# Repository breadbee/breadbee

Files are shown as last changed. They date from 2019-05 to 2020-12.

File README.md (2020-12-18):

# Breadbee

A very small, 32mm x 30mm, ARM Cortex A7 development board that costs about ~$10
to make in low quantities and can be assembled at home with a cheap hot air rework
station. With a [small adapter socket](./hivee) it can be mounted vertically in a standard breadboard.

The breadbee is based on a relatively unknown IP camera SoC, the MSC313E, from a company called MStar
(now part of MediaTek as a subsidiary called SigmaStar).
You might have never heard of MStar but you probably have one of their chips in your TV.

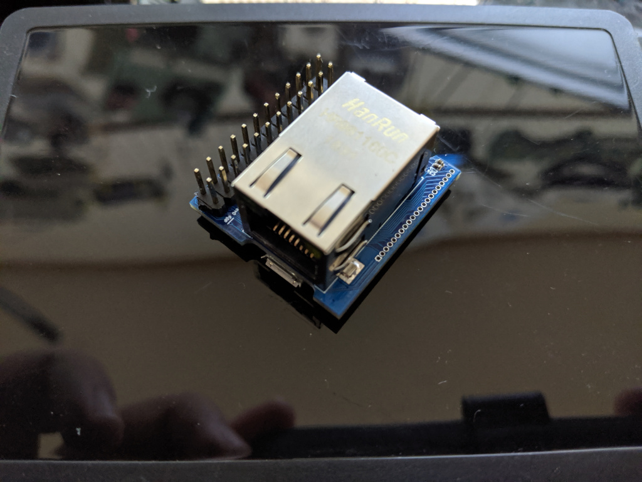
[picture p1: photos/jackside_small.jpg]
Breadbee number one


## Features

These are features that are working:

- ~1GHz Cortex A7 CPU with NEON etc[0].
- 64MB DDR2 (Probably DDR2-1333)
- 128KB SRAM (88KB if you use a MSC313(no e).
- [Bootable, memory mapped SPI-NOR](https://github.com/fifteenhex/linux/blob/msc313e/drivers/spi/spi-msc313-isp.c)
- 100Mbit ethernet.
- [4 x 10bit ADC channels](https://github.com/fifteenhex/linux/blob/msc313e/drivers/iio/adc/msc313e_sar.c)
- [2 x SPI](https://github.com/fifteenhex/linux/blob/msc313e/drivers/spi/spi-msc313.c)
- [1 x I2C (there is possibly one more)](https://github.com/fifteenhex/linux/blob/msc313e/drivers/i2c/busses/i2c-msc313e.c)
- [3 UARTs](https://github.com/fifteenhex/linux/blob/b3c521f8f30c9cc6f9f9c5c87429336d4756dcca/drivers/tty/serial/8250/8250_dw.c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) [1]
- Lots of GPIO. At least one pin with wake up support.
- [RTC](https://github.com/fifteenhex/linux/blob/msc313e/drivers/rtc/rtc-msc313e.c)
- [WDT](https://github.com/fifteenhex/linux/blob/msc313e/drivers/watchdog/msc313e_wdt.c)
- [3 x Timer](https://github.com/fifteenhex/linux/blob/msc313e/drivers/clocksource/timer-msc313e.c)
- [8 x PWM](https://github.com/fifteenhex/linux/blob/msc313e/drivers/pwm/pwm-msc313e.c)
- [SD/SDIO interface](https://github.com/fifteenhex/linux/blob/msc313e/drivers/mmc/host/mstar-fcie.c)
- 2 x ["byte" dma controller](https://github.com/fifteenhex/linux/blob/msc313e/drivers/dma/mstar/mstar-msc313-bdma.c)
- USB PHY
- USB host/device mux
- Faraday FUSBH200 USB *ehci* host controller
- On die temperature sensor. (sorta)
- Hardware RNG. (quality unknown)
- SHA engine. (Runs, not wired to the kernel)
- 8051 "house keeping" MCU. (Basic remoteproc driver)

[0] MStar says it's 800MHz but their own cpufreq code says they clock it to 1GHz
Clocking up to 1.1GHz works fine running dhrystone for hours but causes random lock ups if the spi nor controller and ethernet are fighting for bus access.
[1] One UART is used by the serial console, two more are available via muxing. 

 The chip has a bunch of stuff in it that isn't supported yet:
 - [MUSB USB device controller](https://github.com/fifteenhex/linux/blob/msc313e/drivers/usb/musb/mstar.c)
 - Camera interface, h264 encoder, mjpeg etc.
 - Audio ADC/DAC
 - [Crypto engine](https://github.com/fifteenhex/linux/blob/msc313e/drivers/crypto/msc313-aesdma.c) that seems to be able to do AES encrypted DMA transfers, memory mapped AES encryption etc
 - Some sort of IR decoder that can wake the chip up based on the IR codes it sees.
 - 6 byte unique device ID and efuse for key storage
 - [command queue dma controller](https://github.com/fifteenhex/linux/blob/msc313e/drivers/dma/mstar/mstar-msc313-cmdq.c)

It's full of flashy magic!

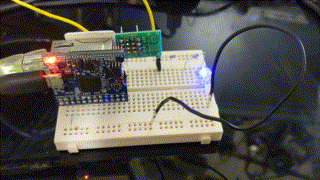
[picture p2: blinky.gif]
PWM blinky


## Power consumption

According to a Kyoritsu KEW 1062 inline with the vbus of a usb cable:

| state | Ethernet on | RTC wake | value |
|---|---|---|---|
| Booted idle  | yes | N/A | 138mA |
| Booted idle  | no | N/A | 113mA |
| Memory sleep | | Yes | 12mA  |

## Board Revisions

- Rev0 - Original version, works.
- Rev1 - Same as rev0 basically but the QFN80 footprint is slightly fixed to not have very thin pads on one side. Rev1 has one weird pad on the QFN80 footprint and an overlapping extra trace on one of the USB signals.

## Motivations

- Networked microcontrollers are a disaster waiting to happen; Many solutions - even commercial ones - use LWIP as the TCP/IP stack with no intention of actually maintaining it, use relatively unknown TLS libraries because of lack of memory, have no memory protection, no isolation between the moving parts.

- There are no solutions yet that can run a real OS like Linux that can be integrated by hobbyists into boards from cheap PCB vendors that don't have show stopping limitations. I.e. the AllWinner V3s is very similar to the SoC used here but it only has one SPI controller that is lost as soon as you put SPI NOR on it. The MSC313E has just enough of the usual microcontroller peripherals to make it useful, comes in a (relatively) easy to work with QFN package, is tiny and costs ~$4.
It is a bit harder to integrate into your designs than a microcontroller that requires a single power supply but all of the information you would need to do so is right here. The schematic for the breadbee is incredibly simple.

- There are single board computers out there that have more cores, more memory etc and are still around $10 but they are over kill for applications where even an ESP32 has enough horse power and they aren't usually something you can integrate into your project without reserving considerable space.

- Why not? The MSC313E is a Cortex-A so getting Linux running from scratch was relatively simple. The peripherals are super weird in places but not totally insane.

## But where's the WiFi!>!!111

The breadbee is meant to be a "minimum viable product" to get the ball rolling. It's impossible to write drivers for the SDIO controller or USB needed for WiFi without a platform to work on. Breadbee is that platform. Once SDIO works there will be an Ampak AP6212 based module to add wifi to breadbees and maybe a respin of the breadbee with the ethernet jack replaced with an Ampak module. 

A simpler alternative consists in using an already supported USB-to-WiFi PCB module given that the breadbee's USB host controller already works fine. This project is documented here.

## Can I have one.. where do I get the chips..

- If you ask very nicely and you are willing to do something like write a nice python library or flesh out drivers for the board it's possible you can have one of the prototype boards for FREE! Get in touch!

- ~~If you just want to buy one the intention is to put the board up on a crowd sourcing site at some point. When that happens that information will be here.~~ [crowdsupply](https://www.crowdsupply.com/daniel-palmer/breadbee) will eventually be selling premade boards. This might take a while though.

- If you want chips to integrate into your own projects and don't have contacts in Shenzhen to get them get in touch and we'll figure something out. If you want 2080 of them getting them isn't a problem. If you want one or two I have a small supply. If the crowd sourcing happens and there is enough money left to buy extra chips to distribute in more accessible ways I will. Since April 2020 chips have now also started to turn on up ebay.

- The gerbers have been uploaded to [OSH park (rev1)](https://oshpark.com/shared_projects/lQ6wt3Dk) ready to order. [OSH park (rev0)](https://oshpark.com/shared_projects/slorKWK0)

## Software

Note that this is all in flux right at the moment. These repos are getting rebase'd fairly often.

### U-boot

There is a basic port of u-boot that so far take over from the MStar IPL and load a kernel from the SPI NOR, write it etc.
See boot process below for more details.

https://github.com/fifteenhex/u-boot/tree/msc313

### Kernel

All of the above features work to some degree in the work tree. Mainlining is in progress but will take time.
For more info please see the linux-chenxing.org [page about mainlining](http://linux-chenxing.org/mainlining.html).

### Buildroot

Combines the u-boot and kernel above with a root filesystem and generates flashable images.
There are some small pieces of a board configuration application called "beecfg" to setup pinmuxing etc.

https://github.com/fifteenhex/breadbee_buildroot

## BoM

[Google Sheet](https://docs.google.com/spreadsheets/d/1FwoQdfAULd6vKPnkrVnFDfQQs8OdsqdwefH3aLVehPo)

## Pin Table

### J2 - Main 2.54mm header

| interrupt | 5v tolerant | notes | alt functions | name |  # |  # | name | alt functions | notes | 5v tolerant | interrupt |
|---|---|---|---|---|----|----|---|---|---|---|---|
| | | | | +5v |  1 | 2  | +3v3 | | | | |
| | | | | gnd |  3 | 4  | pm_gpio4  | | [0] | yes | yes |
| | | | | i2c1_scl  |  5 | 6  | i2c1_sda  | | | | |
| yes | | | ej_tck, pwm4 | spi0_cz |  7 | 8  | spi0_ck | ej_tms, pwm5 | | | yes |
| yes | | | ej_tdo, pwm6 | spi0_di |  9 | 10 | spi0_do | ej_tdi, pwm7 | | | yes |
| | yes | | | sar_gpio2 | 11 | 12 | sar_gpio3 | | | yes | |
| | yes | | | sar_gpio1 | 13 | 14 | sar_gpio0 | | | yes | |
| | yes | cs | spi0_cz, pwm0 | fuart_rx  | 15 | 16 | fuart_tx  | spi0_ck, pwm1 | clk | yes | |
| | yes | mosi, [1] | spi0_di, pwm2, uart1_rx | fuart_cts | 17 | 18 | fuart_rts | spi0_do, pwm3, uart1_tx | miso | yes | |
| | | | | sr_io7 | 19 | 20 | sr_io6 | | | | |
| | | | | sr_io5 | 21 | 22 | sr_io4 | | | | |
| | | | | sr_io3 | 23 | 24 | sr_io2 | | | | |

0: This is a special pin that has to be explictly unlocked to be set. It seems to be intended for powering down the main CPU. It might move on rev1.

1 - When fuart is mux'd in it's also possible to mux'in uart1 and get a working rx only
    second uart here.

### J4 - Misc/High speed interfaces

* Note the USB and SD/SDIO are not guaranteed to work as literally no care was taken to route those signals properly on rev0. 

| name | #  | alt functions | 5v tolerant | interrupt | notes |
|---|----|---|---|---|---|
| +3v3 | 1  | | | | |
| sd_d3 | 2  | spi1_do | yes | | miso  |
| sd_d2 | 3  | spi1_di | yes | | mosi  |
| sd_d1 | 4  | spi1_ck | yes | | clk |
| sd_d0 | 5  | spi1_cz | yes | | cs |
| sd_cmd | 6  | | yes | | |
| sd_clk | 7  | | yes | | |
| pm_sd_cdz | 8  | | | yes | |
| gnd | 9  | | | | |
| +5v | 10 | | | | |
| usb_dm | 11 | | | | |
| usb_dp | 12 | | | | |
| gnd | 13 | | | | |
| sr_io15 | 14 | | | | |
| sr_io14 | 15 | | | | |
| sr_io13 | 16 | | | | |
| sr_io12 | 17 | | | | |
| sr_io11 | 18 | | | | |
| sr_io10 | 19 | | | | |
| sr_io9 | 20 | | | | |
| sr_io8 | 21 | | | | |

### Test Points

- The audio pins are broken out to a series of test points on the left side of the parts size of the board.
- pm_irin is broken out to a test point on the ethernet jack side of the board.

## Using JTAG

JTAG is enabled at boot up on the spi0 pins by the u-boot SPL.

## More technical info

[linux-chenxing](http://linux-chenxing.org) has more info about mstar/sigmastar socs.

## Articles etc

[A nice blog entry from Willy about his experience building boards](https://wtarreau.blogspot.com/2020/09/breadbee-build-your-own-single-board.html)

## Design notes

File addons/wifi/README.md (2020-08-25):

# How to simply add WiFi to a breadbee

This is far from being of high quality, but provided little effort, it is possible to add a simple WiFi module to the breadbee.

There are a wide variety of cheap USB modules provided as a small 12.3x13mm PCB with 4 pins on one side and 2 on the other one. These modules work from 3.3V and are connected via USB. Usually they do not have any antenna but one can be connected to the two pins on one side.

Such modules are widely used in WiFi cameras and various consumer appliances, and are usually available from $1.50 to $5.00 depending on the modules. Just search for RTL8188EUS, RTL8188ETV, RTL8188FTV, MT7601U to find a few such devices. Most of them use the exact same footprint and pinout.

The breadbee board features a USB 2.0 controller with a port accessible on the J4 connector:

Pin |  Function
----|-----------
  1 |   +3.3V
 11 |   USB-DM
 12 |   USB-DP
 13 |   GND

Modules which contain a connector can be directly connected to these pins using 4 wires, as shown below:

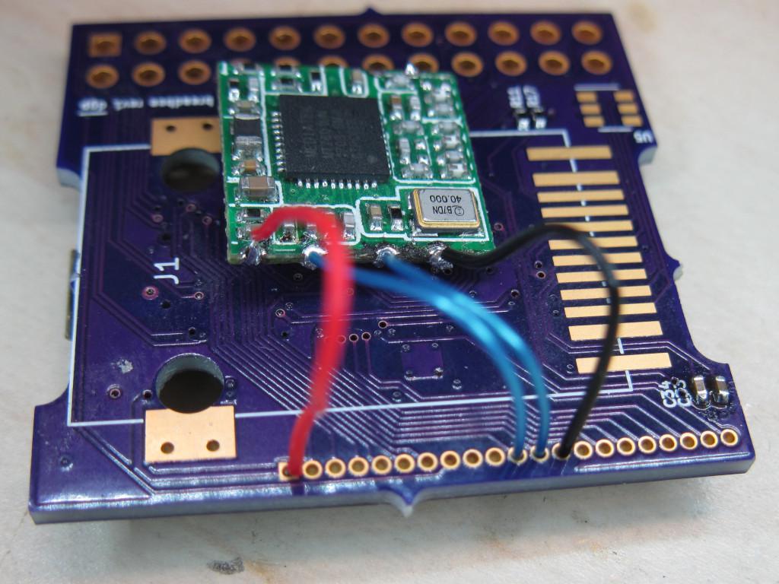
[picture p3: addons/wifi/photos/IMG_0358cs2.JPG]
on the board without RJ45
  

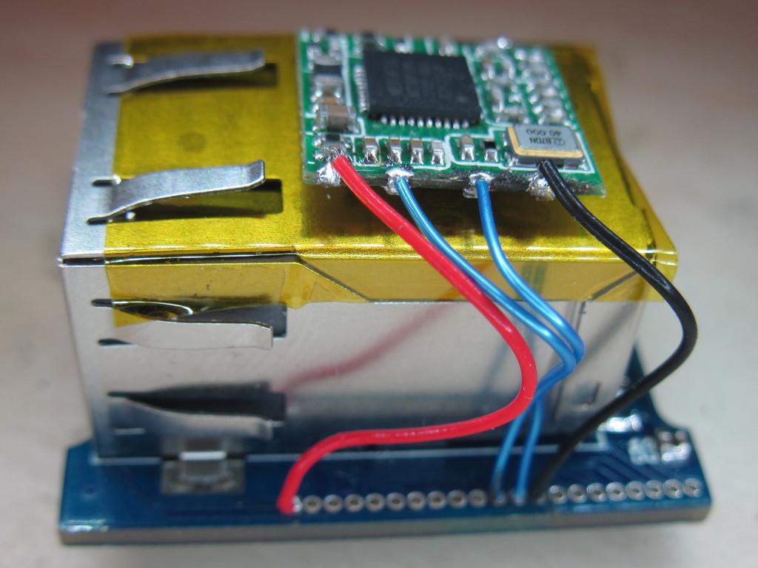
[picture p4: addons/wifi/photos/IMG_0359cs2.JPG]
on the board with RJ45
  

In order to get a cleaner assembly, it is recommended instead to build a breakout board for the module. This is what is proposed in this directory.

The board was designed using Eagle CAD, for which the files are available in the cad directory but the schematic and board layout are also provided as PDF and PNG in the output directory. The board contains a PCB-printed antenna. These antennas can be efficient but are quite complex to design because they depend on the PCB's material and thickness, and the surrounding metal parts. There is a widely available literature on the subject but given the author had no experience there, a first quick-and-dirty attempt was made, losely inspired by the following documents after carefully studying them, and taking into account the constraints of the PCB's size and the fact that the one used here was single-sided:
 - https://www.nxp.com/docs/en/nxp/application-notes/AN11994.pdf
 - http://www.idc-online.com/technical_references/pdfs/electrical_engineering/A%20Highly%20Reliable%20Platform.pdf
 - https://www.cypress.com/documentation/application-notes/an91445-antenna-design-and-rf-layout-guidelines
 - https://www.autodesk.com/products/eagle/blog/everyday-app-note-design-efficient-antenna-rf-layout/
 - https://e2e.ti.com/support/wireless-connectivity/bluetooth/f/538/t/626343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

The board was made using cheap 1.6mm FR4 PCB and provided great results (mesured as the ability to connect and maintain a correct TCP transfer rate at a given distance). Without any antenna, such boards barely connect more than 5-10 meters away on the same floor. With the PCB's antenna, it was possible to maintain roughly 20-25 Mbps between two different stairs.

It is important to make sure the board will be printed to the appropriate dimensions: the J4 connector has a 1mm pitch, and even a 1% error would cause 0.1mm error over 1cm and could be an issue to connect the pins while keeping the boards perfectly tight. It is wise to verify the alignment when drilling the 4 holes (0.4 to 0.5mm max):

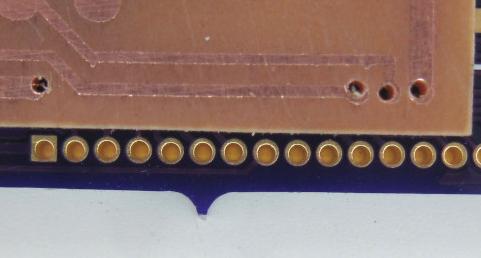
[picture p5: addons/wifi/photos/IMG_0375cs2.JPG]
aligning the boards
  

Then the board may completely cover the J4 connector to keep wires short:

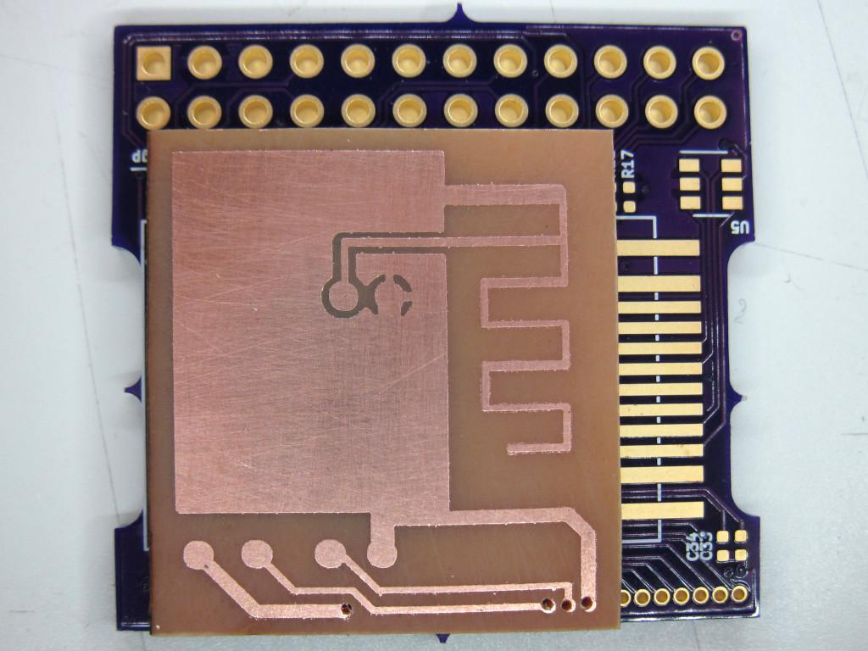
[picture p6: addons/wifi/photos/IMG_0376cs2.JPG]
boards stacked
  
 
The module just needs to be soldered on 6 points. It's recommended to make sure that no contact may be made against the ground plane underneath the module. In case of doubt, a small piece of Kapton tape may be placed between the two, or the module can be kept slightly elevated during soldering.

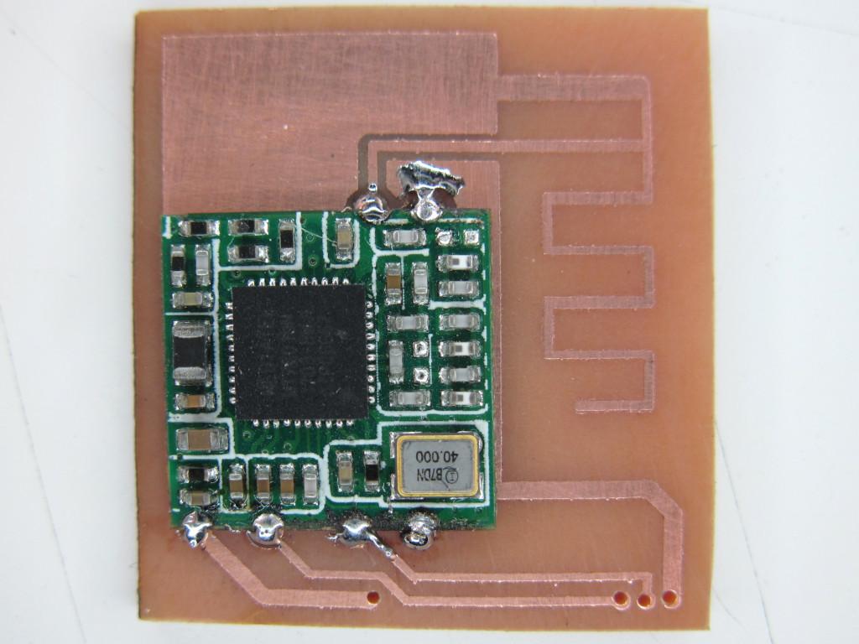
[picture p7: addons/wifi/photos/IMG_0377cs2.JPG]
module installed on bare board
  

The resulting assembly can then be pressed against the breadbee and connected using resistor tails. Alternately, it may be placed on top of the RJ45 connector using short wires. It would also be possible to place it on the SoC side, but in this case it is important to be very careful about insulation.

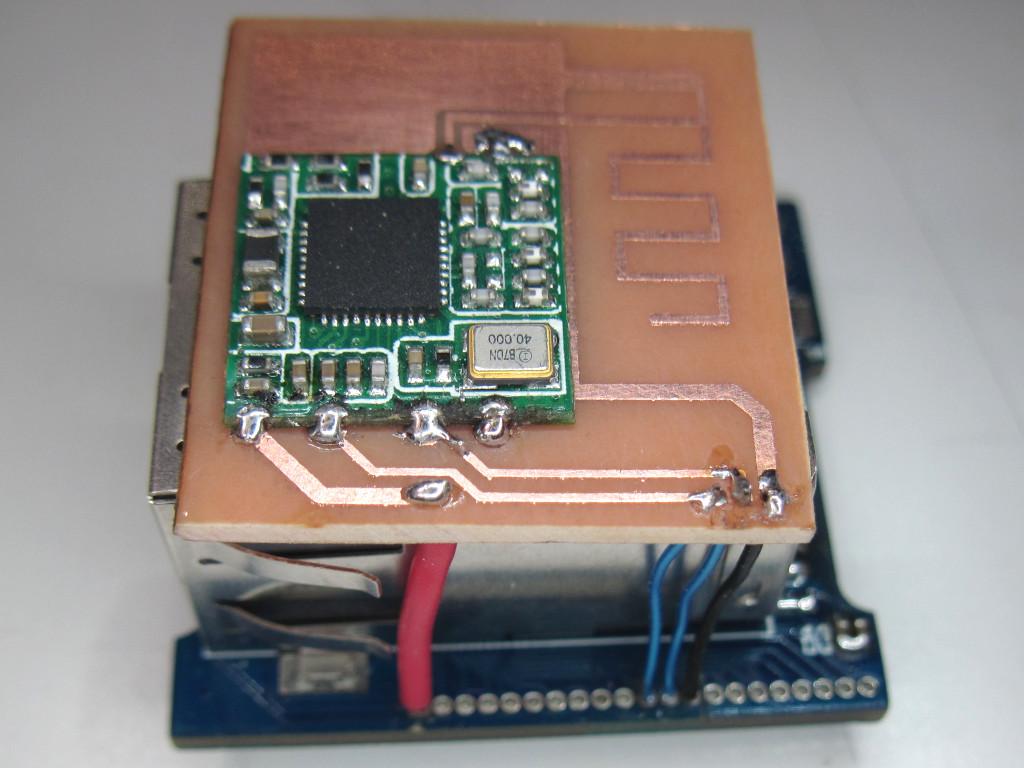
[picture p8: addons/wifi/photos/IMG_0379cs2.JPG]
module installed on RJ45
  

# Testing the board

First, the kernel needs to enable the UHCI controller. For this, a uhci0 DTB overlay should be used. The author doesn't know how to use overlays, so instead the following patch was applied to the DTS:

```
diff --git a/arch/arm/boot/dts/infinity3-msc313e-breadbee.dts b/arch/arm/boot/dts/infinity3-msc313e-breadbee.dts>
index d7445db8a388..8f5d111baca7 100644
--- a/arch/arm/boot/dts/infinity3-msc313e-breadbee.dts
+++ b/arch/arm/boot/dts/infinity3-msc313e-breadbee.dts
@@ -24,3 +24,7 @@ chosen {
 &pm_uart {
 	status = "okay";
 };
+
+&uhc0 {
+	status = "okay";
+};

```

From this point, the USB controller should be enumerated with its I/O memory address:
```
# dmesg | grep hcd
[    0.921383] fotg210_hcd: FOTG210 Host Controller (EHCI) Driver
[    0.934328] fotg210-hcd 1f284800.uhc: Faraday USB2.0 Host Controller
[    0.940675] fotg210-hcd 1f284800.uhc: new USB bus registered, assigned bus number 1
[    0.948413] fotg210-hcd 1f284800.uhc: irq 48, io mem 0x1f284800
[    0.962221] fotg210-hcd 1f284800.uhc: USB 2.0 started, EHCI 1.00
[    1.397675] usb 1-1: new high-speed USB device number 2 using fotg210-hcd
[   15.032213] usb 1-1: reset high-speed USB device number 2 using fotg210-hcd
```

Using `usb-devices` it should be possible to enumerate the device:

```
# /etc/bin/usb-devices 

T:  Bus=01 Lev=00 Prnt=00 Port=00 Cnt=00 Dev#=  1 Spd=480 MxCh= 1
D:  Ver= 2.00 Cls=09(hub  ) Sub=00 Prot=01 MxPS=64 #Cfgs=  1
P:  Vendor=1d6b ProdID=0002 Rev=05.08
S:  Manufacturer=Linux 5.8.1-bbw fotg210_hcd
S:  Product=Faraday USB2.0 Host Controller
S:  SerialNumber=1f284800.uhc
C:  #Ifs= 1 Cfg#= 1 Atr=e0 MxPwr=0mA
I:  If#=0x0 Alt= 0 #EPs= 1 Cls=09(hub  ) Sub=00 Prot=00 Driver=hub

T:  Bus=01 Lev=01 Prnt=01 Port=00 Cnt=01 Dev#=  2 Spd=480 MxCh= 0
D:  Ver= 2.01 Cls=00(>ifc ) Sub=00 Prot=00 MxPS=64 #Cfgs=  1
P:  Vendor=148f ProdID=7601 Rev=00.00
C:  #Ifs= 1 Cfg#= 1 Atr=80 MxPwr=160mA
I:  If#=0x0 Alt= 0 #EPs= 8 Cls=ff(vend.) Sub=ff Prot=ff Driver=mt7601u
```

Note that this is with an MT7601U board above. An RTL8188 will likely show something different. If this works, we can go on with enabling WiFi client support in the kernel.

# Enabling WiFi support in the kernel

The following config options were added on top of a kernel 5.8 config that was operational for the breadbee board. Note that we're speaking about the breadbee development tree, not yet 100% mainline. Only MT7601 was added there. Another option is available for RTL8188, but was not tested (look for `R8188EU`).

```
CONFIG_SYSTEM_DATA_VERIFICATION=y
CONFIG_ASN1=y
CONFIG_WIRELESS=y
CONFIG_CFG80211=y
CONFIG_CFG80211_REQUIRE_SIGNED_REGDB=y
CONFIG_CFG80211_USE_KERNEL_REGDB_KEYS=y
CONFIG_CFG80211_CRDA_SUPPORT=y
CONFIG_MAC80211=m
CONFIG_MAC80211_HAS_RC=y
CONFIG_MAC80211_RC_MINSTREL=y
CONFIG_MAC80211_RC_DEFAULT_MINSTREL=y
CONFIG_MAC80211_RC_DEFAULT="minstrel_ht"
CONFIG_MAC80211_LEDS=y
CONFIG_MAC80211_STA_HASH_MAX_SIZE=0
CONFIG_FW_LOADER_PAGED_BUF=y
CONFIG_EXTRA_FIRMWARE="mt7601u.bin"
CONFIG_EXTRA_FIRMWARE_DIR="/lib/firmware"
CONFIG_FW_LOADER_USER_HELPER=y
CONFIG_WLAN=y
CONFIG_WLAN_VENDOR_MEDIATEK=y
CONFIG_MT7601U=m
CONFIG_KEYS=y
CONFIG_CRYPTO_AEAD=m
CONFIG_CRYPTO_AKCIPHER=y
CONFIG_CRYPTO_GF128MUL=m
CONFIG_CRYPTO_NULL=m
CONFIG_CRYPTO_RSA=y
CONFIG_CRYPTO_CCM=m
CONFIG_CRYPTO_GCM=m
CONFIG_CRYPTO_CTR=m
CONFIG_CRYPTO_CMAC=m
CONFIG_CRYPTO_GHASH=m
CONFIG_CRYPTO_HASH_INFO=y
CONFIG_CRYPTO_LIB_ARC4=m
CONFIG_ASYMMETRIC_KEY_TYPE=y
CONFIG_ASYMMETRIC_PUBLIC_KEY_SUBTYPE=y
CONFIG_X509_CERTIFICATE_PARSER=y
CONFIG_PKCS7_MESSAGE_PARSER=y
CONFIG_SYSTEM_TRUSTED_KEYRING=y
CONFIG_SYSTEM_TRUSTED_KEYS=""
CONFIG_ASSOCIATIVE_ARRAY=y
CONFIG_CLZ_TAB=y
CONFIG_MPILIB=y
CONFIG_OID_REGISTRY=y
```

The MT7601U driver requires a firmware (`mt7601u.bin`). As there was no convenient place to store this firmware in the image, it was simply embedded in the kernel and retrieved from /lib/firmware on the build host.

Once rebuilt with these options, the kernel may be booted again and the module loaded:

```
# modprobe mt7601u
# lsmod
Module                  Size  Used by
mt7601u                45056  -2
mac80211              274432  -2
libarc4                16384  -2
```

Note the use count of -2 which was not yet diagnosed. Either it results from one of the module options to explicitly prevent from unloading the module, or it's a bug. As such if a new module option is needed, one needs to reboot the board and try again. Regardless, once the module is loaded, it works pretty fine.

# Building a stripped down wpa_supplicant

If one wants to connect to a WPA-protected network (which is very likely), the `wpa_supplicant` utility will be needed. This one will usually be huge by default as it supports a lot of protocols and options. However it also supports disabling many of them to reduce its footprint. It may be configured this way:

```
$ printf \
        "CONFIG_DRIVER_NL80211=y\n"             \
        "CONFIG_READLINE=y\n"                   \
        "CONFIG_NO_STDOUT_DEBUG=y\n"            \
        "CONFIG_NO_SCAN_PROCESSING=y\n"         \
        "CONFIG_BACKEND=file\n"                 \
        "CONFIG_NO_CONFIG_WRITE=y\n"            \
        "CONFIG_NO_CONFIG_BLOBS=y\n"            \
        "CONFIG_NO_LINUX_PACKET_SOCKET_WAR=y\n" \
        "CONFIG_IEEE80211W=y\n"                 \
        "CONFIG_NO_RANDOM_POOL=y\n"             \
        "CONFIG_GETRANDOM=y\n"                  \
        "CONFIG_IEEE80211N=y\n"                 \
        "CONFIG_IEEE80211AC=y\n"                \
        "CONFIG_NO_ROAMING=y\n"                 \
        "CONFIG_IBSS_RSN=y\n"                   \
        > wpa_supplicant/.config

$ CC=/path/to/cross-compiler LD='$(CC)' CFLAGS="-MMD -Os" \
  make -j$(nproc) -C wpa_supplicant
```

The development version of openssl and libnl will have to be installed in the sysroot. The resulting binary is still large (~300 kB) but compresses well in a squashfs (~120 kB).

A minimal config file like this one is sufficient:

```
# cat /etc/wpa_supplicant-wlan0.conf
network={
 ssid="lab-test"
 scan_ssid=1
 key_mgmt=WPA-PSK
 proto=WPA RSN
 psk="Lab-Test-Passw0rd"
}
```

Starting wpa_supplicant with the wlan0 interface using this config should now work:

```
# wpa_supplicant -B -iwlan0 -c/etc/wpa_supplicant-wlan0.conf -P/var/run/wpa_supplicant-wlan0.pid
# iw dev
phy#0
 Interface wlan0
   ifindex 3
   wdev 0x1
   addr 00:0c:43:12:34:56
   ssid lab-test
   type managed
   channel 7 (2442 MHz), width: 40 MHz, center1: 2452 MHz
   txpower 20.00 dBm

```

Once this is done, the wlan0 interface should appear as `UP` and an address may be retrieved using dhcpcd:

```
# ip li show dev wlan0
3: wlan0: <BROADCAST,MULTICAST,UP,LOWER_UP> mtu 1500 qdisc mq state UP mode DORMANT group default qlen 1000
    link/ether 00:0c:43:12:34:56 brd ff:ff:ff:ff:ff:ff
```

From now on, everything is specific to the distro in use.

# Final words

It's very easy to add such a module that might be salvaged from a dead camera (like the one used above), and the breadbee has the excellent taste of placing the pins in the same order as the module's so there's no risk of getting anything wrong. The breakout board is not strictly required, a previous successful attempt was made using 3cm wires on both the `ANT` and `GND` pins that were bent over the RJ45 connector. As a side note, this howto was written with dumps retrieved from the breadbee over Wifi! Try it, it's easy and fun. You won't look at your ESP32 the same way after that :-) Happy hacking with the breadbee!

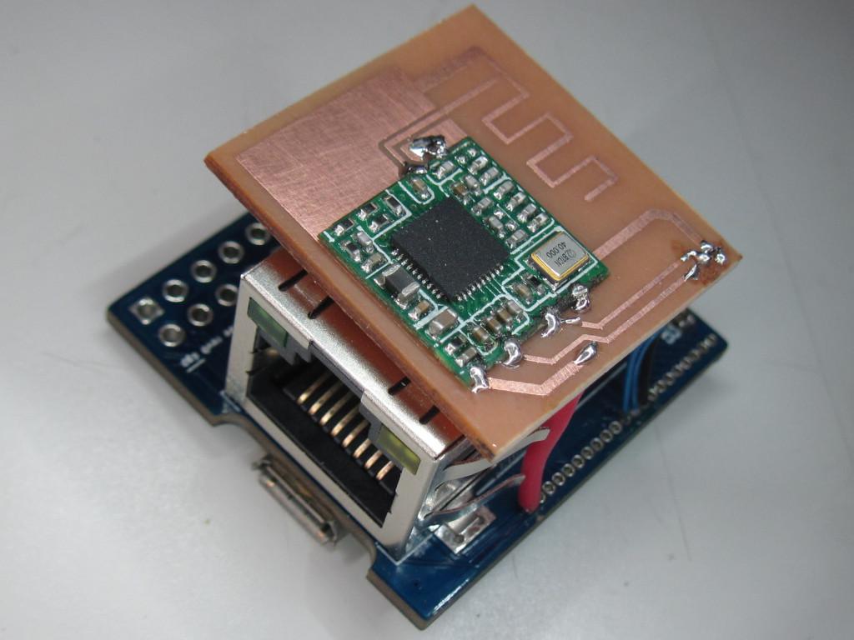
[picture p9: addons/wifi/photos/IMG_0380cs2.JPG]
final board


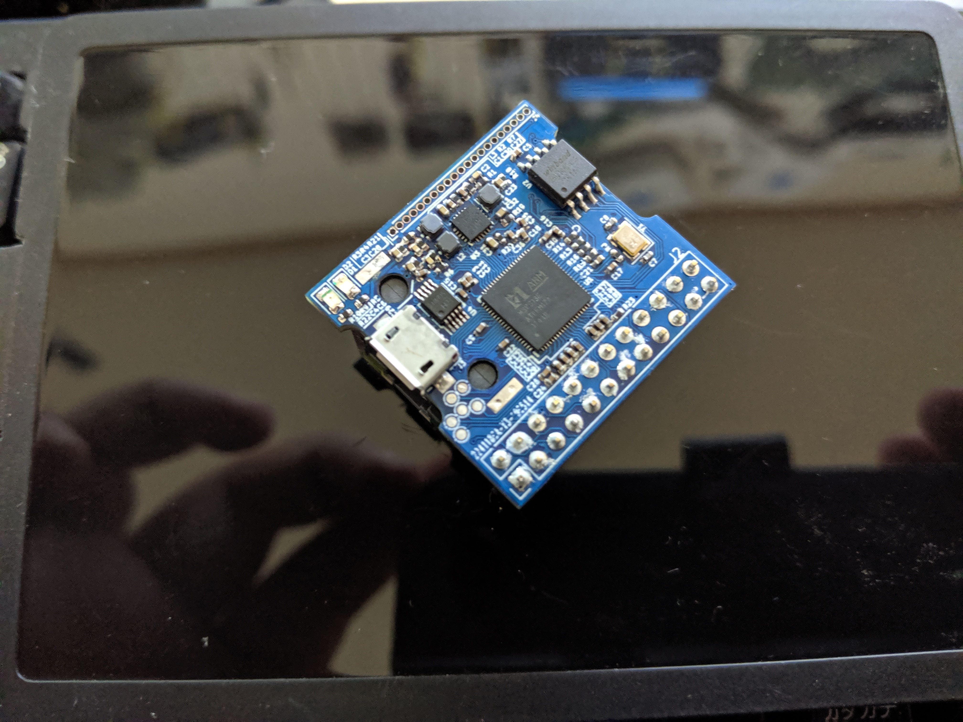
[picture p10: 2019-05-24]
photos/partsside.jpg

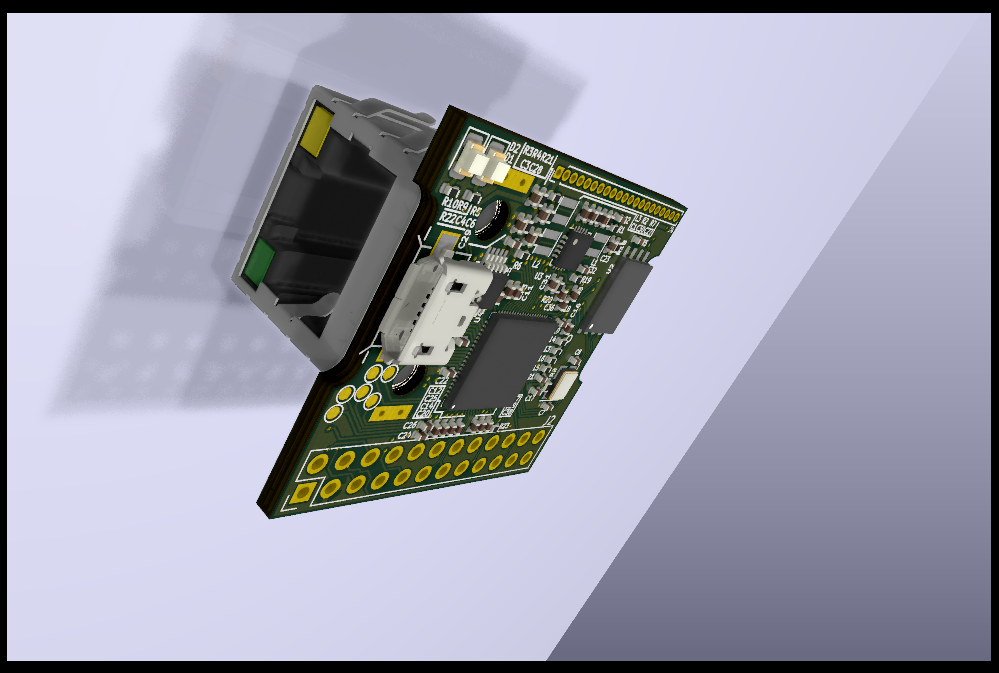
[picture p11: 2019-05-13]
renders/breadbee_front.png

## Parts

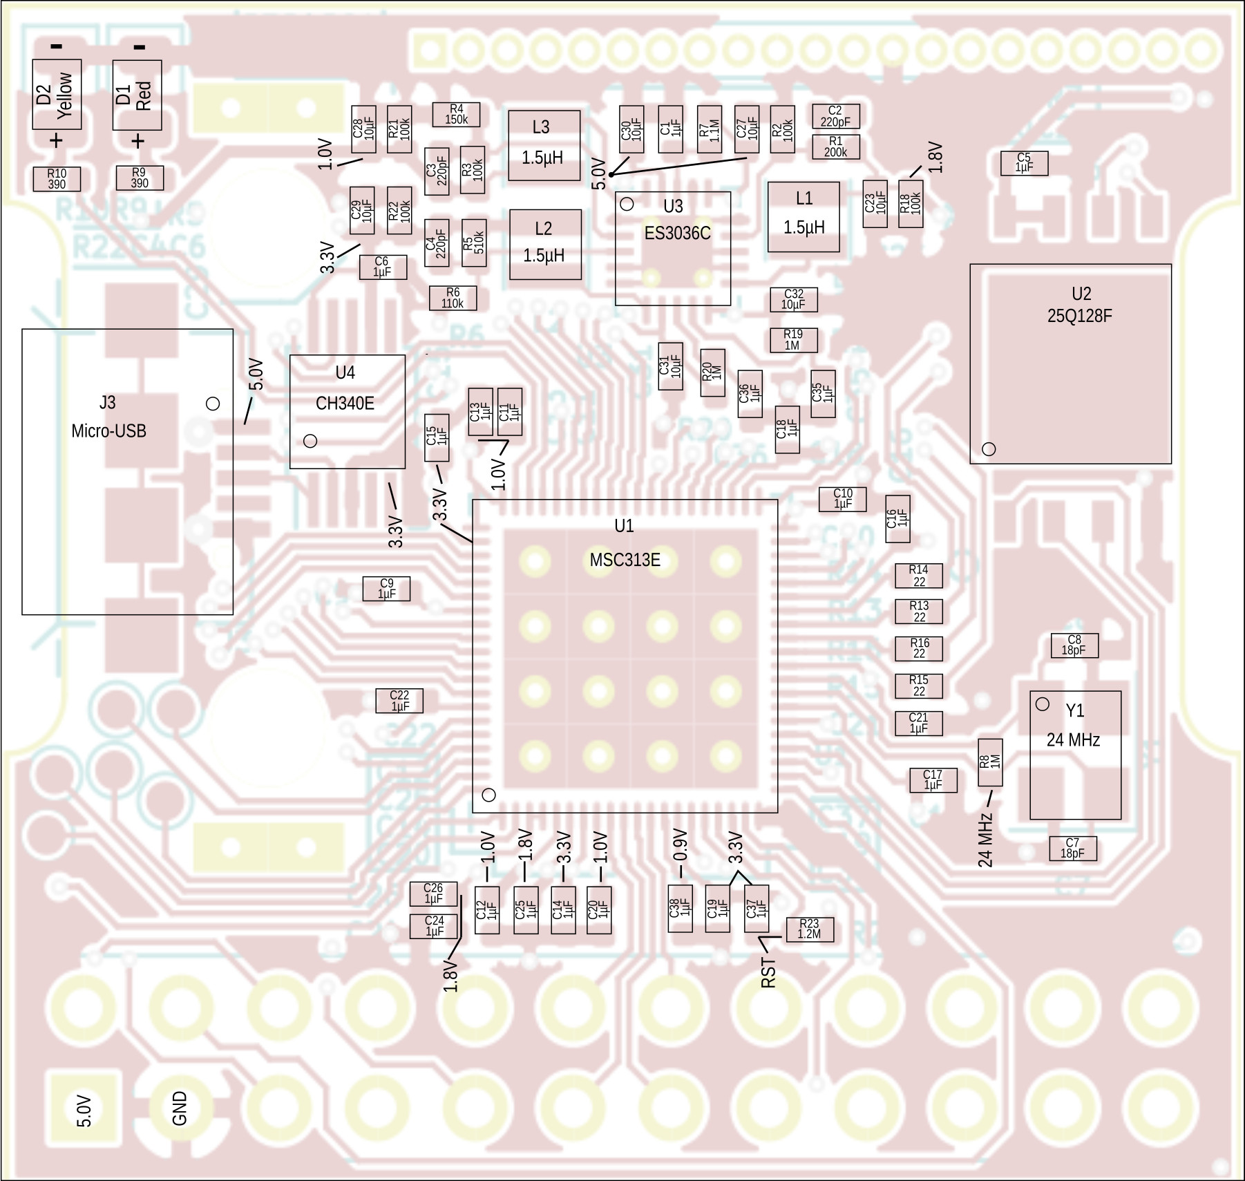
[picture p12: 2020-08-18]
howtobuild/components-copper.jpg

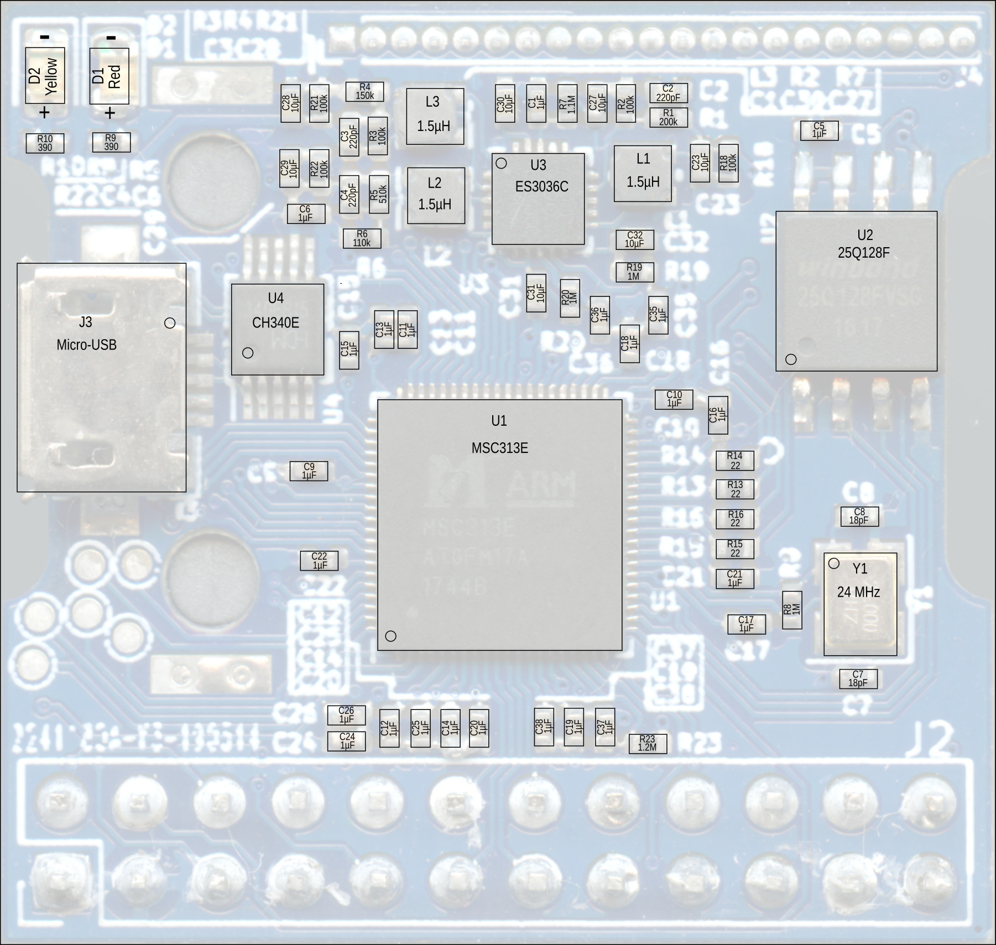
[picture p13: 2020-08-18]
howtobuild/components-photo.jpg

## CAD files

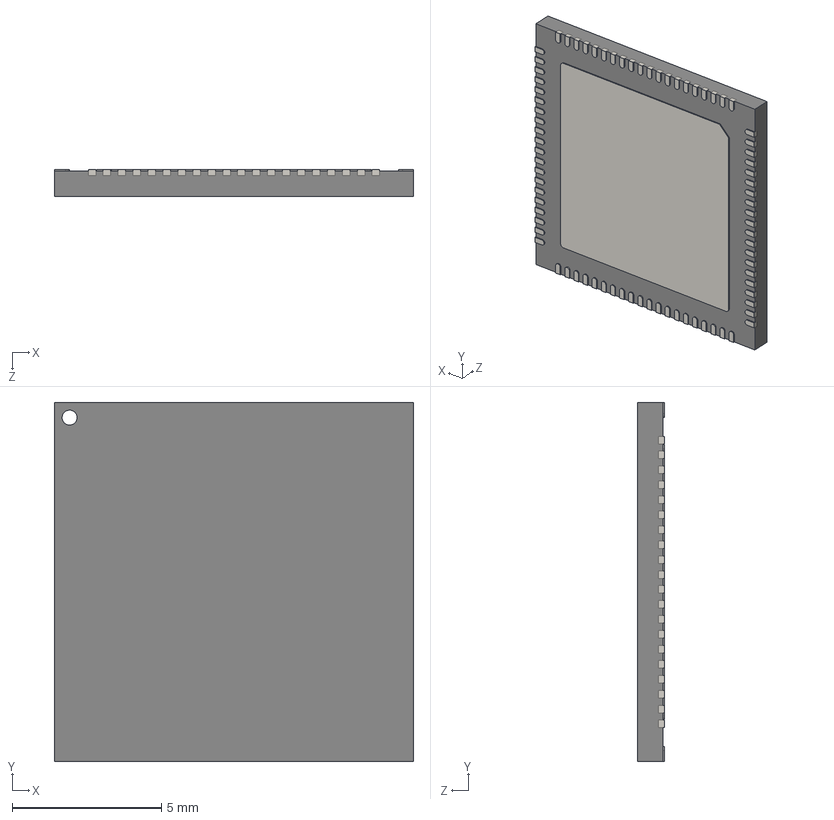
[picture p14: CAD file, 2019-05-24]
3d/qfn80/qfn80.step
12.0 x 12.0 x 0.9 mm

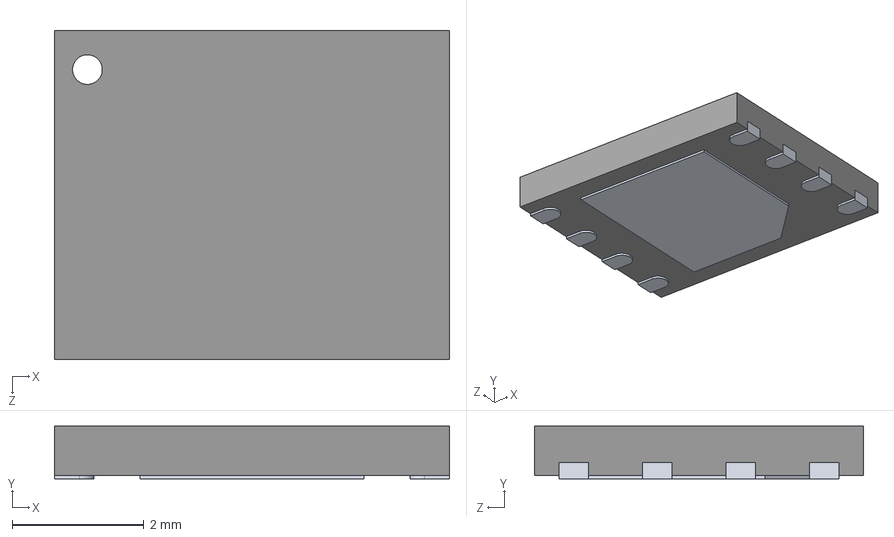
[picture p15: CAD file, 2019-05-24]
3d/wson8/wson8.STEP
6.00 x 0.8 x 5.00 mm
User Library-WSON-8_Case
User Library-WSON-8_Pad x 8
User Library-WSON-8_Power pad

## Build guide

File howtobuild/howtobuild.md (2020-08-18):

** this isn't finished yet **

# How to build a breadbee

These are some rough instructions base on how I've been hand assembling boards. If you have a reflow oven or a pick and place machine you can probably do better on your own..

## What you need

- The parts
- A hot air rework tool. Cheapies work just fine.
- Tweezers, poking implements.
- Side cutters.
- Kapton tape.
- Sharp small craft knife blade with tape wrapped around it so that it looks like some sort of prison weapon.
- Solder paste. Low temp stuff is the easiest to work with but can result in brittle joints for the usb connector. If you use low temp solder you probably want some epoxy to reinforce the usb connector.
- Solder wick.
- A soldering iron with a knife tip or if you can't get a knife tip a small point. A small point isn't ideal but you won't have space to get a massive chisel tip into the places you need.
- Flux in with bottle a little brush applicator or gel style SMD rework flux. Flux pens aren't ideal.
- Proper flux cleaner or at least IPA.
- Old tooth brush.
- USB camera or lupe.
- Time
- Patience

## Technique

Generally building a board in stages isn't good. Constantly reheating the board means that all of the components are going through multiple heating cycles and can lead to other components wondering off and the board getting thrown out of the window. However, realisticly you aren't going to be able to put doing the QFNs and all of the passives in one go.

Building in with the steps below should result in usable boards. Maybe not production quality super high quality ones but ones that will work for your projects.

A component layout was done by hand and superimposed on top of the finished board photo or the copper tracks. The different versions are available in the "components-*" files present in the current directory. If you're used to assemble boards with components reference on paper, the printable version might be useful. The source of these files is provided in components-layout.svg and is editable under Inkscape.

## 0 - Tape the board down

If you have a nice PCB vice then use that. Otherwise tape the board down to your work surface with kapton tape. If you think you will need to rotate the board while soldering find something with some weight you can tape it to that won't melt or suck all of the heat out of the board while soldering. I use a square of MDF covered in kapton tape.

You must tape it down as the board is very small and you will not be able to overcome the surface tension of the components to reposition them if you don't. Instead you'll be desperately trying to poke a component into place and the little board will be moving around instead. Also if you're like me and knudge stuff by mistake you'll be happy the board was taped down and not on the floor with all of the components smeared across it.

## 1 - Mount the MSC313E

This may seem counter intuitive, mounting the most expensive and hardest to get part first, but it becomes really hard to work with the MSC313E once the surrounding components are mounted. If you manage to destroy the board while mounting other components later you can always pull it off and use it on the next one.

The high pin count might be a bit intimidating but actually it's one of the easiest parts of the build. Basically you just need to smear a thin square layer of solder paste that covers both the small outter pads and the big center pad. You don't have to be super precise here. You don't want to have too much excess but having too little paste is worse than too much.

Once you have a nice square patch of solder paste drop the MSC313E onto it making sure the pin 1 dot lines up with the indicator on the silk screen. If you don't get it aligned now don't bother repositioning it. You don't really need to and you'll just get paste everywhere. As long as it's generally inside of the border silk screen you're ok.

Now with your hot air tool waft hot air around the whole board. You should see that the solder paste that is still visible liquidifies slightly and starts to look a bit like a t-1000 is going to form out of it. Once this happens you should stop wafting the hot air everywhere and focus it over the MSC313E. If you have a nozzle that covers the whole area just holding it above should be good enough. If you have a smaller nozzle move in a circular motion over the chip to make sure everything is heated up. You should now see the chip ping into place and sit right in the middle of the silk screen boarder and round blobs of excess solder forming around the edges. You should use your tweezers or other pokey thing now to tap it a bit to push out the rest of the excess solder and confirm that it's located itself. If you poke it up a little bit you should see it instantly move back where it was. If the chip seems slightly rotated or offset that means it's located itself one or two pads off. You should be able to poke it in the opposite direction and see it click into the right place. You need to poke while keeping the solder molten. Once you're happy it's in the right place back off with the hot air and take a little break. Don't worry about all of the solder balls around the edge for now. Also don't worry if some solder escaped and got onto surrounding pads.

Once you have your breath back get you solder wick and cut the end into triangle with a wide edge and sharp point. Start wafting hot air at the edge of the MSC313E you're going to clean up first and wait until the solder is molten again. Once the solder is molten again brush the edge of the chip with your solder wick edge while tracking with the hot air. You should see all of the balls of excess solder disappear and leave you with a nice clean edge. You probably won't be able to see how nice it looks right now because of all of the flux from the paste but you should have no bridges and clean connections to the chip. The key here is to be gentle. The wick will move the chip if you aren't careful. You only really want to pass the wick through the balls of excess solder to mop them up not really have it come in contact with the chip itself.

Now that the excess solder is gone you can take another little break and wait for everything to cool down again. Once it looks like everything solid again take some of your flux remover and cover the area around the MSC313E. Take your old tooth brush and scrub away the flux. If you have good eyes you should be able to see if there are any bridges, blobly bits, dry pads etc. Once you've done the solder wick trick a few times you should always end up with something that's pretty much perfect. Anyhow if you do have bridges or blobs you just need to apply some flux and then drag your soldering iron along the edge to neaten everything up. You want to do this before mounting any more components as you won't have the space later.

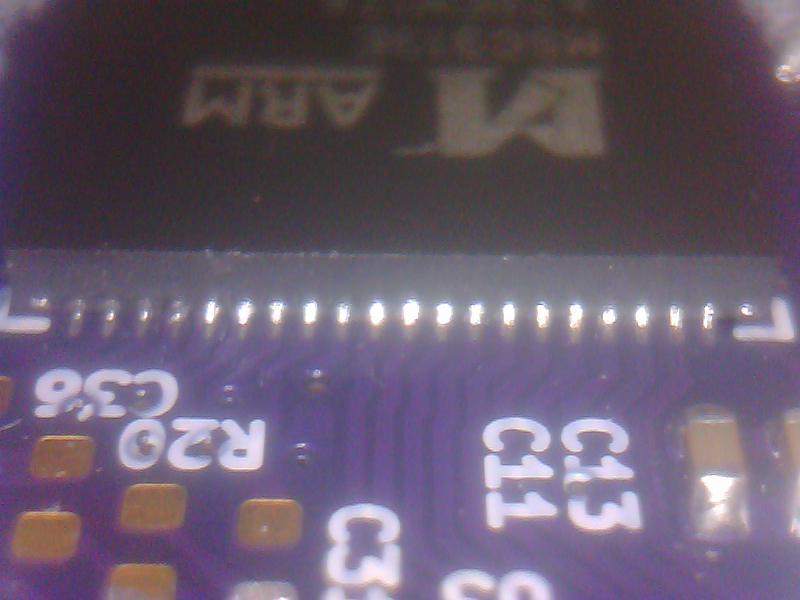
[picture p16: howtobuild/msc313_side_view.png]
msc313e solder joints


# Mount the EA3036C

Use exactly the same process as the MSC313E.

# Mount the inductors

# Mount a lot of the 1uf caps

Start from C11 and go counter clockwise up to C37, dab paste and place the caps and then reflow them

# Mount the R23, and some more 1uf caps

# Mount the crystal and support components

# Mount more 1uf caps

# Mount the two 10uF caps and resistors

# mount c23 and r?

# mount the big row of passives above the EA3036C

# Mount the left side of the block of passives to the left of the EA3036

# Mount the right side of the block of passives to the left of the EA3036

# mount the CH341e

# mount the USB connector

# mount the leds

# First test

# Mount the two jumpers

# mount the two caps

# Mount the Ethernet jack

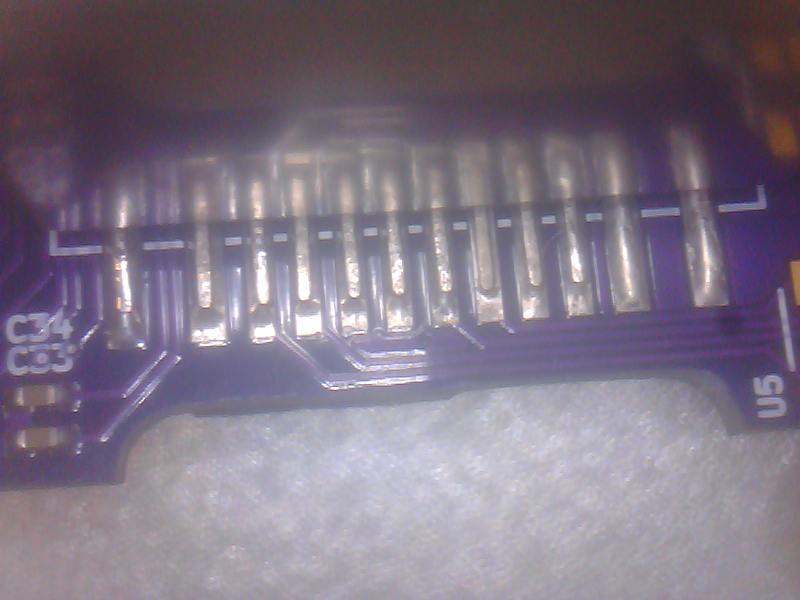
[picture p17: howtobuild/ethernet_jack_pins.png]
ethernet jack pins


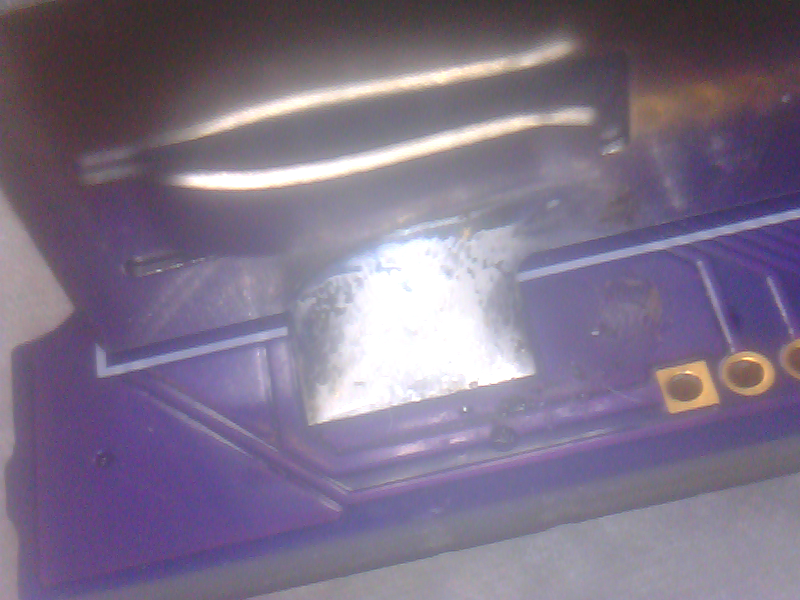
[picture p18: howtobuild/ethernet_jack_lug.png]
ethernet jack lug


# mount the spi nor

You can mount the SPI NOR with out anything on it as long as you have a programming clip. You need to write it first.

# flash the spi nor

# Profit?

## Smoke test

If possible plug the board into a bench power supply with the current limit set at ~200mA.
If the board is generally working you should see current draw of ~10mA for a short time and then between 80mA and 100mA.

If the current draw stays at around ~10mA the processor is probably running but the initial boot stage isn't getting loaded
from NOR flash. If the current draw is ~0mA then you probably have a power supply issue.

If you don't have a bench power supply one of those cheap USB power meters works as well but without the protection
of being able to limit the current if you have something really wrong. You should probably try with a USB charger and
not the USB port of your expensive computer initially.

Generally speaking nothing should be getting hot once you plug it in. If board is getting hot when you power it up kill the
power and check for shorts etc.

## Fingers crossed..

If the magic smoke didn't come out you should be good to plug it into your computer now.

A few moments after plugging it in you should see the usb->serial chip get registered. If you see no USB activity or your OS
is complaining that it couldn't enumerate the device you might need to check the USB connector soldering.

The current u-boot will turn on the D2 led (top left corner) when it starts so you can see the processor has gotten that far
so you might be able to see that your board is running even if the usb->serial part isn't coming up.

# Power supply debugging

## Check the input power is getting from the USB connector to the board:

- Check there is 5v on pin 1 of J2

If this is missing check your USB connector soldering.

## Check the outputs from the EA3036C are right:

- Check there is ~1v on C28
- Check there is ~3.3v on pin 1 of J4
- Check there is ~1.8v on C23

If any of these rails are missing or the wrong voltages you'll need to check over the power supply area.
Missing voltages might be soldering issues. Wrong voltages might be component value mistakes.

## Check that internal LDO of the SoC is alive

- Check there is ~0.9v on C38

If this isn't present check around the SoC to see if there are any obvious bad joints.

# Boot/NOR debugging

If you don't see any output from u-boot it's possible your board is running but the processor can't boot
from the NOR for some reason.

If the processor is working there is always some output on serial. Unfortunately it's at 38400 baud
and comes usually before the usb->serial is registered. To get around this plug the board into USB and let it
register, setup minicom to 38400 baud etc. Then poke a wire into pin 2 of J2 (3.3v) and touch it to either C37
or R23 on the end that is connected to the reset signal. If the processor is running you should get "E:CD".
Nothing after "E:CD" means the contents of your NOR flash is bad or the NOR flash is not connected properly.

# Clock debugging

If you have a scope poke probe at R8 to see if you have the 24MHz clock. 
If you don't have a scope you can check with a multimeter by probing at R8 to see if you have ~1.8v there.

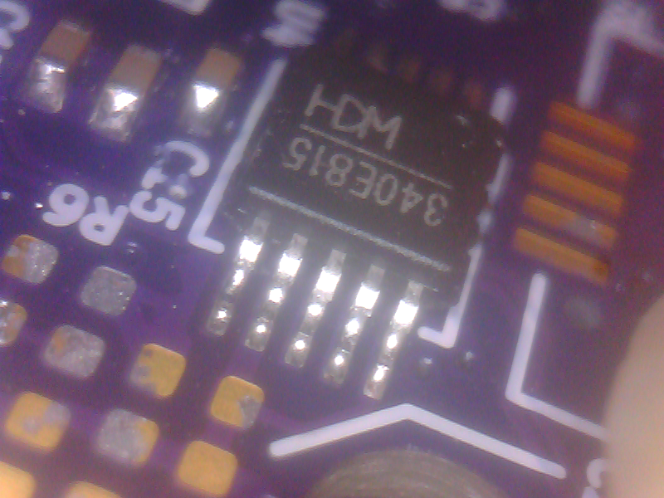
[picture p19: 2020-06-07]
howtobuild/ch340e_side_view.png

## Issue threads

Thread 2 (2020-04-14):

[Question] PoE capability

StKob, 2020-04-14:
Are there any plans to build support for PoE? This board could be used for quite many applications where it could be powered via ethernet plug while communicating. For example: diy weather sensors.

fifteenhex, 2020-04-15:
I think getting the transformer and HV step down onto this board would be pretty hard. There isn't a lot of space and it was already a pain to make it this small and within the bounds of what the cheap Chinese PCB fabs can produce.

StKob, 2020-04-15:
Could you actually make board 32 x 32 and fit that stuff? Although I don't know if that would make big price difference.

fifteenhex, 2020-04-15:
I don't think the additional 2mm helps that much. At 4 layers without expensive stuff like blind vias (vias that are only present on some layers not through the entire board) there isn't much more space to route anything.

Looking at commercial PoE modules (i.e. https://www.alibaba.com/product-detail/12w-Output-Power-Over-Ethernet-PoE_112394905.html) I think it'd be physically impossible to get it onto the board without making it twice as big.

If there was an RJ45 jack that had the ethernet magnetics and PoE parts cramed into it then maybe it'd be possible to swap the RJ45 jack over. I don't see any other way it could work.

StKob, 2020-04-15:
Something like this?
https://www.te.com/global-en/products/connectors/intersection/industrial-rj45/industrial-rj45-integrated-magnetic-jacks/ethernet-jacks-with-integrated-magnetics-and-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

igut, 2020-04-15:
Using a POE capable Ethernet PHY you could extract the power from the cable to 4 additional pins from where an external POE module could provide power to many different applications and to the device itself. I have in mind this kind of modules: http://www.r-tone.com/en/ProductList.asp?SortID=35 The same approach can be seen on Banana-pi,  Rock-pi etc. This would make the BreadBee desirable for a broad range of applications!

fifteenhex, 2020-04-16:
I understand what you guys as saying. This is my opinion on it:

- If you can find a RJ45 jack that has the magnetics and the PoE bits fully integrated that is the same size as the current one I can see if it's possible to make that work somehow. The problem is that most RJ45 jacks have pins that go through the board and there is no room in the current design for anything else to go through the board as both sides are fully packed. The current jack was the only SMD jack I could find that was cheap and didn't need cut outs in the board.

- If you want a board like this with PoE I would get some of those solder in modules, take the breadbee schematic and make a little board that solders right onto the back of it. If you don't mind the older version of the chip used here that runs at 800mhz and not 1ghz you can get them for about $2.5 or I can give you a few.

StKob, 2020-04-16:
I've found something like this: http://www.link-pp.com/upload/file/20190307/20190307135160306030.pdf

fifteenhex, 2020-04-16:
That doesn't include the electronics to actually do the PoE part.

StKob, 2020-04-16:
Ok, but you can then provide pins from that. Then it would be possible to make optional daughter board.

fifteenhex, 2020-04-20:
> optional daughter board.

I think once you have a daughter board you might as well use an in-line PoE splitter with a microusb output.

sbridger, 2020-04-23:
> I think once you have a daughter board you might as well use an in-line PoE splitter with a microusb output.

I disagree. Splitters are neither small, or cheap (relatively). Having the transformer centre taps available to feed an external circuit is ideal for me.
1) No added cost when it's not needed
2) You are not committed to any particular way of doing poe. The standards compliant way, is not what many hackers would be doing. (eg putting 4 breadbees in a box, you just feed 5V down the poe)
3) possibly putting a bridge rectifier / footprint on the breadbee would allow any little smps to be wired up. The bridge is not on many little smps boards.

fifteenhex, 2020-04-23:
>Having the transformer centre taps available to feed an external circuit is ideal for me.

The center taps of the transformer are available on C33 and C34.

> 3. possibly putting a bridge rectifier / footprint on the breadbee would allow any little smps to be wired up. The bridge is not on many little smps boards.

I don't think there is enough space to do that and keep the trace width and spacing large enough that it can be produced on the cheap pcb services without making a mess.
I think there might need to be a bit of consideration on how to stop the PoE supply from back feeding into the usb too.

If someone whats to doodle out what is needed. How it'll fit etc I'm happy to try to add it.

sbridger, 2020-04-24:
OK, I will have a look.

btw , (on schematics) "M" is used for megohm resistors, "m" is milliohm.

Might be an idea to have RC filter on AVDD_node

On sch, I see you aren't taking the usb out to the usb connector.

Perhaps an option would be to put CH330, (8 pin SOP) over the usb resistors to USB_d?

Thus the usb could connect if resistors are in, or a CH330 could be fitted (easy to solder/remove sop8)
These [adaptors](https://www.aliexpress.com/item/32814218082.html) could be used for usb master

fifteenhex, 2020-04-24:
>btw , (on schematics) "M" is used for megohm resistors, "m" is milliohm.

mmm ok. I'll update those values.

>On sch, I see you aren't taking the usb out to the usb connector

Initially I didn't expect to be able to reverse engineer the usb part so I didn't bother.
I'm not sure if a CH330 would fit. I think a SOP8 is bigger than a MSOP10. But I think there could be some jumpers somewhere to connect the usb data lines to the on board usb port.

fifteenhex, 2020-05-19:
Closing this for now.

moqmar, 2021-04-21:
Also interesting would be support for 5V passive PoE, that should be a lot easier to implement?

fifteenhex, 2021-04-22:
> Also interesting would be support for 5V passive PoE, that should be a lot easier to implement?

If you want to do the schematic changes for it I don't mind trying to route it in the PCB.

moqmar, 2021-04-23:
Oof, seems like the [HR961160C](https://datasheet.lcsc.com/lcsc/1811141110_HANRUN-Zhongshan-HanRun-Elec-HR961160C_C55683.pdf) more or less just grounds the spare pins and thus doesn't expose the neccessary pins for any kind of PoE...

So, I guess without changing the RJ45 connector, PoE is not gonna happen...

moqmar, 2021-04-23:
[Abracon ARJ-102S](https://abracon.com/Magnetics/lan/ARJ-102S.pdf) and or [Molex 0938098046](https://static6.arrow.com/aropdfconversion/4a4189b549f64118f5c998b09980b07fb6c595a7/0938098046_modular_jacks_plug.pdf) should work, but they cost at least twice as much.

fifteenhex, 2021-04-23:
> Edit 3: it seems like both are protruding through the PCB, so I guess that's not really feasible for this project? Or can we raise the PCB somehow by soldering another one onto it for that part...

That's the main issue I think. The current connector is the only one I could find that is SMD (can't have pins through the board) and doesn't need a cutout in the board. I think an SMD connector without the transformers + an external SMD transformer packager would work but I think it would be too long.

moqmar, 2021-04-23:
Soo, the old connector is 26.6mm long (including pins). Most transformer packages (like the TG110-RPE5N5LF) are 9.53mm long (including pins), and there's the TE 6339191-1 or some others being 16.48mm long (including pins), yielding 26.01mm (which isn't achievable as the pitch doesn't match - I couldn't find a 1.27mm pitch jack with LEDs yet).

If we can then fit some tiny connector for pins 4/5, 6/7, VCC and GND, those could be bridged for passive 5V PoE, or converted with a tiny daughter-board with a RPMH5.0-1.5 for higher-voltage passive PoE, or even 802.3af Mode B PoE (requiring some additional resistors and).

fifteenhex, 2021-04-24:
>  I couldn't find a 1.27mm pitch jack with LEDs yet).

Without LEDs works.. the leds on the current connector aren't connected as the chip doesn't expose pins to drive them.

moqmar, 2021-04-24:
If we can give up on the shielding and CAT 3 is enough as well then there's the 14.5mm long Amphenol 73304-111LF. I'm not sure though if that's such a good idea...

Then there's the Amphenol RJSSE-5380 which is 18.29mm long including pins, but the pins are 2.57mm long so they can be shortened a bit - it's more of a hack though then.

moqmar, 2021-04-25:
[Würth 7498210002](https://www.mouser.de/datasheet/2/445/7498210002-1723983.pdf) 😀

It solves all of our problems, but holy shit is it expensive, almost 9 €...

Closed 2020-05-19.

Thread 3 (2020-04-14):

Battery, Solar, & Native Low Power Mode support

PracticalCode, 2020-04-14:
Are there any plans to build support for a battery 'hat'?

And\or are there any plans to build support for a solar 'hat', which could perhaps recharge the battery?

Along those lines, plans to support the low power mode (allowing the unit to 'sleep', and wake once an hour, then back to sleep.)

This board could be used for quite many applications where it could be used for remote \ standalone operations. For example: diy weather station, doorbell, security 'nanny' cam (especially once you get the camera supported.)

fifteenhex, 2020-04-15:
>Are there any plans to build support for a battery 'hat'?

There are plans for the Wifi enabled version to have a proper PMIC that has a charger etc.
The issue is getting a PMIC with the right default voltages as all of the very cheap ones (AXP, Injoinic) are apparently ordered in 2000+ batches with the customers required default voltages set and the ones I can get have the wrong voltage for the DDR memory.

With that said I have also looked at possibly using the same 3 in 1 DC-DC buck chip with a lipo charger with power path (see https://github.com/fifteenhex/dbmbyhd)) as an alternative as I don't want to keep having to build 2000 of things.

>And\or are there any plans to build support for a solar 'hat',
>which could perhaps recharge the battery?

I have no plans to do that myself but there's no reason someone else couldn't. If you don't need mppt etc I think just having a proper PMIC with a good input range would work. If someone wants to detail want is needed to do it right I can try to integrate it into the wifi version.

>Along those lines, plans to support the low power mode (allowing the unit to 'sleep',
>and wake once an hour, then back to sleep.)

The chip apparently contains everything to go into DDR refresh only with the CPU turned off that should achieve what you want. The RTC is listed as a wake up source in the register descriptions I can find too so potentially you could set an RTC alarm. I have managed to get the CPU to turn off and it's power consumption is ~10mA like that. I haven't managed to get it to turn back on yet.
Also this version of the board has no control over the voltage rails. A proper PMIC would allow the core voltage to be scaled and disabled totally when sleeping which should bring it down a bit more.

>doorbell, security 'nanny' cam (especially once you get the camera supported.)

For camera applications IP camera boards with the same family of chip are much cheaper:

https://item.taobao.com/item.htm?spm=a230r.1.14.27.68d32e0et9vGsD&id=562051542010&ns=1&abbucket=17#detail

The uboot/kernel for this board runs on those modules. However I wouldn't hold your breath on camera support. I've worked out where a lot of the hardware is and how it's sort of plugged together but actually doing something with it is another story.

juehv, 2020-04-16:
I'm highly interesed in a SBC with suspend to ram capabilities, too :)
That would be very nice for my battery powered projects!
Looking forward to your crowd funding campain 👍

fifteenhex, 2020-04-26:
Update on this:

Suspend to ram is now working to the point that it suspends and the RTC is able to wake it back up via an alarm but the boot rom gets stuck on reentry. My usb current meter shows 0.00A when it's sleeping so the consumption must be pretty low.

fifteenhex, 2020-04-26:
Another update:

Working to the point that the kernel is restarting now. Hangs just after. Needs some love to work out what is locking it up but pretty close.

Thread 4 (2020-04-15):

Development setup

kadamski, 2020-04-15:
What development setup do you have for the board? My understanding is that the ethernet works in u-boot so the kernel and rootfs can be loaded over tftp/nfs, right?

The IPL, u-boot SPL and u-boot itself must be on the SPI NOR currently and when changing u-boot this could be broken it has to be desoldered, reflashed and soldered again or there is some easier option? Or can u-boot proper be loaded from JTAG so only IPL/SPL need to be on the flash?

fifteenhex, 2020-04-16:
Sorry for the brevity. Writing this while eating on my lunch break..

>What development setup do you have for the board?

tftp for the breadbee itself. The other chips have a bigger bootrom that can load a blob from sd card so I have combined uboot + kernel blob that gets loaded into memory and then I tell uboot to bootm the image thats in memory.

>My understanding is that the ethernet works in u-boot so the
>kernel and rootfs can be loaded over tftp/nfs, right?

Yes. the SD card doesn't work in uboot yet so ethernet or loading over serial are the only options.
The usb ip already has a driver in uboot so that should also work with some hacks.
The current setup gives you a rescue image with a really small kernel and rootfs that is just enough to reload the main image from network, usb or sd.

>when changing u-boot this could be broken it has to be desoldered, reflashed and soldered again

As long as you don't break the IPL and the u-boot SPL image breaking u-boot isn't a problem as the SPL is configured to be able to load the main uboot over serial. That has saved me a few times.
For times I have broken the IPL/SPL I have used a clip to reflash the chip in place. It's far from ideal.

Long term the bootrom seems to have a UART boot mode. Working out how it works and writing a flashing program are on my todo list.

kadamski, 2020-04-17:
> The current setup gives you a rescue image with a really small kernel and rootfs that is just enough to reload the main image from network, usb or sd.

Could you explain a little bit how this rescue image works? How can we choose to boot from it instead of the main one? This is meant to be used when kernel/rootfs does not start, right? There is no such rescue for broken u-boot?

> the SPL is configured to be able to load the main uboot over serial.

What is the protocol for that? How to enter this boot mode?

How about JTAG? My understand is that u-boot SPL enables it so it should be possible to load u-boot via openocd, isn't it?

kadamski, 2020-04-17:
Also, is https://linux-chenxing.org/isp/ somehow related? My understanding is that there is some i2c -> spi bridge to flash the spi-nor but I did not understand how to use that. Could that be used for recovering broken flash? Is there some dedicated i2c bus for that? Does it always work or it has to be enabled somehow? Do you know any details on that?

fifteenhex, 2020-04-17:
> Could you explain a little bit how this rescue image works?

u-boot will stop autoboot if you type "bzzbzz". From there you can load a kernel from tftp or run bb_boot_rescue and have it load the rescue environment. It would also be possible to have it load if a gpio is grounded or something.

>There is no such rescue for broken u-boot?

If the u-boot image is broken in flash the SPL will complain it couldn't load it and wait for uboot to be sent via serial using the ymodem protocol. Recovering from a u-boot image that works but crashes isn't possible at the moment but it could be implemented with a gpio to tell the SPL to always wait for ymodem.

>How about JTAG? My understand is that u-boot SPL enables it so it should be possible to load u-?>boot via openocd, isn't it?

Yes, that worked last time I tried it. You can load uboot proper into memory and jump to it.

fifteenhex, 2020-04-17:
> Also, is https://linux-chenxing.org/isp/ somehow related?

All mstar chips seem to be able to become an i2c slave on pm_uart that allows programs to be loaded into memory, registers poked etc. I have the dongle and the windows tool but I haven't needed to use it yet. It should be possible to use that to load a program into memory to flash a blank device or recover a bricked one.

I think working out how the UART load in the bootrom works is the best solution as it wouldn't need special hardware tools.

kadamski, 2020-04-17:
> I think working out how the UART load in the bootrom works is the best solution as it wouldn't need special hardware tools.

But for the i2c method, there is an existing tool so the i2c communication it uses could be sniffed and we could understand how that works. How can UART loader in the bootrom be worked out? Do you have some knowledge about it?

fifteenhex, 2020-04-17:
> But for the i2c method, there is an existing tool so the i2c communication it uses could be sniffed

That's true and other people have sniffed the i2c protocol used by other mstar parts so it's possible it'll be the same. With the current board it's not easy to test though as the usb->uart is on those pins.

>How can UART loader in the bootrom be worked out? Do you have some knowledge about it?

Disassembling the bootrom. I did this to find out how to boot from SD card on the other chips.
It would be mostly a case of finding where the bootrom reads from the UART and working out the path to work out what it wants to see. I'm building some tools (https://github.com/fifteenhex/noriflex) so I can easily mess around with the NOR flash to allow me to more easily work on the boot up parts. I intend to replace the mstar IPL binary as well at some point so everything is opensource.

kadamski, 2020-04-17:
> That's true and other people have sniffed the i2c protocol used by other mstar parts so it's possible it'll be the same. With the current board it's not easy to test though as the usb->uart is on those pins.

Ach, I see. Maybe it would be good to have at least some test points added for that on the future revisions of the board, then? However it should still be possible to solder two wires to the ch340e even now. So the console_tx and console_rx is used as SDA/SCL in this mode?

I still don't understand how to enable this i2c on those pins, though.

>  I'm building some tools (https://github.com/fifteenhex/noriflex) so I can easily mess around with the NOR flash to allow me to more easily work on the boot up parts.

That's cool. What do you plan to put on the other side? Something that will emulate the SPI-nor?

fifteenhex, 2020-04-17:
> Ach, I see. Maybe it would be good to have at least some test points added for that on the future

Yep. I learned about the tool after the board design was done and ordered.

> I still don't understand how to enable this i2c on those pins, though.

I think it's done by pulling one of the pins down on reset to disable the uart and switch in the i2c slave it has.

>That's cool. What do you plan to put on the other side? Something that will emulate the SPI-nor?

There will be a mux chip that can switch an spi nor chip between the target board and a programmer. So I can mess modify the nor flash, switch it to the target, test it, modify it again,..
It'll make testing a lot easier.

fifteenhex, 2020-04-18:
I wired up the uart to i2c on another chip in the series and the i2c looks exactly the same as what other people have found:

kadamski, 2020-04-19:
I was looking in the documents and forums to understand how this i2c debug mode could be enabled. It couldn't be simpler, though. Apparently the UART peripheral is detecting I2C START condition without switching modes, quite cool. My understanding is that UART_RX is SCL and UART_TX is SDA, right?

The ch340e does not have a pull-up on TX line, I think. Does it allow any bitbanging? I know the ch341 does support i2c but on other pins than UART so that would be tricky.

fifteenhex, 2020-04-19:
>My understanding is that UART_RX is SCL and UART_TX is SDA, right?

I'll check. I plugged in the wires and flipped them until i2cdetect saw something. The flashrom tool already has a driver for the mstar spi over i2c which it used. I managed to read out the contents of a chip with it yesterday.

> The ch340e does not have a pull-up on TX line, I think. Does it allow any bitbanging?

I don't think the ch340e does bit bang but I think it could be faked by using RTS to pull the line low to create the SCL signal and the CTS pin to read the SDA line. The transmit parts of i2c would need to be done by sending out bytes from the uart and getting the SCL timing right to frame the byte as a low or high bit.

It would be very tricky and slow but it would only ever be for recovery, wouldn't need any new hardware etc.

kadamski, 2020-04-20:
> I'll check.

That is how the brief describes it:
```
Signal Name | Signal Type | Function                                                  | Pin Location
UART_RX     | Input       | Debug Port for UART Receiver *or Slave I2C Serial Clock*  | 18
UART_TX     | Output      | DebugPort for UART Transmitter *or Slave I2C Serial Data* | 19
```

fifteenhex, 2020-04-20:
Well spotted. I haven't looked at it in ages.

I don't think I'll get a response but I've asked the ch340e maker it has a bit bang mode or anything.
I'm not finding an alternative FTDI or otherwise chip that has documented bit bang and is the same size.

kadamski, 2020-04-20:
Btw, it seems like the Conn_01x21 could be extended by 2 pins and could have access to raw console_tx and console_rx pins so that some cheap external i2c controller (or even other breadbee) could be easily used for recovery. Unless you have some specific reason to keep this connector exactly 21 pin wide.

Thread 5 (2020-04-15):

[Question] FLASH sizes

lal12, 2020-04-15:
I wondered a bit about the FLASH size. A 16MB flash seems to be a bit small to me. After uboot and kernel it's only 12.5MB, which I would guess is just enough for a base system. Even a minimal embedded linux base system (busybox + ulibc ...) can quickly take up a significant amount of that. So it depends a bit on what game you want to play but for a more RPI and ease of use for anything direction it should have at least 64MB, probably would be better. I would imagine many people would like to work with PHP or Python on it. NodeJS probably won't work anyway with less than >=80MB RAM. which would very quickly go beyond the 12MB rootfs size.

Since this is just a first dev board it might not be that important, but if there is not enough FLASH to develop for such more Higher Level languages/tools it might be a bit annoying later. Though do I understand correctly that the SoC supports an SD Card interface?

fifteenhex, 2020-04-16:
Sorry for the brevity. Writing this on my lunch break...

Currently 16MB NOR gets you uboot, one small kernel + uclibc based rescue environment, one bigger kernel + glibc based environment with python3. There are two issues with going above 16MB; 1 - If the addressing mode gets switched and the kernel crashes it'll probably get stuck at reboot. The AllWinner V3s has this problem. I suspect this chip also has this problem but I haven't tested it. 2 - The memory mapped part of the memory is only 16MB. In the kernel it's possible to revert to CPU driven access for the non-memory mapped part but the performance will be worse for anything in the bit after 16MB. For example loading python3 from flash with CPU access is ~4s and the CPU is pegged. With DMA memory mapped access it's around 2s and the CPU clock isn't ramped up.

SD card works and there is a little wing board for the fine pitch header that has an SD socket, USB socket and gpio breakout. I think for people that need more storage maybe one of those NAND with an SD card interface chip like the Rock Pi S is using is a good solution.

kadamski, 2020-04-17:
@fifteenhex For the first problem, some of the chips support 4byte opcodes which does not require mode switching so there is no problem with reset. I mean the SPI_NOR_4B_OPCODES flag in the kernel. This, however, would require CPU driven access for the flash, I guess, as the memory mapped peripheral does not probably support those opcodes?

fifteenhex, 2020-04-17:
I'll take a look at the registers for the flash controller again. It's possible to set the access opcode so maybe we can trick it into mapping different 16MB blocks into the memory window so it's all memory mapped. I didn't look too hard into it because I thought it would be a minefield of issues with the boot rom.

lal12, 2020-04-17:
Two off topic questions:
- Is there an (inofficial) datasheet for the SoC? I couldn't find anything yet.
- Regarding the "Get in touch!" part in the README how to contact you? EMail on your github profile?

fifteenhex, 2020-04-17:
> * Is there an (inofficial) datasheet for the SoC? I couldn't find anything yet.

linux-chenxing.org is where I'm collecting info. There is one complete datasheet for a different chip that has many of the same registers etc. Aside from that it's a case of trawling through the vendor code

> * EMail on your github profile?

Yep.

Closed 2020-05-19.

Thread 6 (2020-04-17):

[Question] Boards for sale?

ConnorRigby, 2020-04-17:
I help run an open source, embedded linux framework called nerves (https://www.nerves-project.org/ , https://github.com/nerves-project) i'm very interested in the breadbee and would like to know if it's possible if i can buy a board off of you in an effort to get a port of our stack up and running on it. I see that you have a want for a nice python library that i could also help get started.
Thanks for your time.

fifteenhex, 2020-04-18:
Your project looks interesting.

Boards aren't for sale yet. My freebies for people that will help out offer still stands but I'm out of PCBs at the moment. I've ordered more but with the current situation it might be a little while.

AdamKeher, 2020-04-25:
Do you know where I can purchase a few MSC313E SoC IC's?

I want to spin my own version of the board with some additional peripherals but can't see any options other than trying to lift them of existing boards.

fifteenhex, 2020-04-25:
There are still a few sets of 5 for $10 on ebay.

AdamKeher, 2020-04-25:
Could I hassle you for a link. I've searched every MSTAR item on ebay and it seems to be filtering them out in Australia. I can find other MSTAR IC's but no MSC313E.

fifteenhex, 2020-04-25:
Sure:

https://www.ebay.com/itm/5pc-SMT-QFN-IC-chip-MSC313E/153876332882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

https://www.ebay.com/itm/5pc-SMT-QFN-IC-chip-MSC313E/153876332882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

AdamKeher, 2020-04-25:
Thanks, that worked.

Closed 2020-06-06.

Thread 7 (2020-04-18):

[TODO] Work out i2c/UART bootloader for flashing/recovery.

fifteenhex, 2020-04-18:
- Work out how the UART bootloader works so black or bricked boards can be flashed.

- Add the needed jumper/jumpers to the board so that it can be triggered.

kadamski, 2020-04-19:
Is the bootrom dump available somewhere to look at it?

fifteenhex, 2020-04-19:
It's here.

https://github.com/fifteenhex/mc200c2camerahacks/blob/master/msc313ebootrom.bin

Since playing with the i2c thingy I'm wondering if the "UART" bootstrap pin setting I have might mean just stopping it booting to interfering with the i2c. Hopefully it isn't. Loading over UART normally is much better than spi over i2c with a weird hacky interface.

fifteenhex, 2020-04-19:
Note to self: UART reading is in the M5 bootrom but not the I3 one. I3 probably doesn't have UART boot.

kadamski, 2020-04-20:
> I3 probably doesn't have UART boot.

So for the msc313e, the only recovery option would be via i2c, right?

fifteenhex, 2020-04-20:
> So for the msc313e, the only recovery option (in case of broken flash content) would be via i2c, right?

The SD card should be bootable. I just haven't looked hard enough yet for the pin to make it try to boot it. The strings in the I3 rom for that match up with the M5 rom and I'm already using it on the M5.

kadamski, 2020-04-20:
About the bootrom deassembly, have you worked out something already? Where is the code stored in the address space, what is starting point, where is vector table stored? Anything that could help me get up to speed?

The SRAM is at 0xa0000000, peripherals are somewhere above 0x1f000000, RAM is at 0x20000000, but the beginning of the binary uses some 0xeaXXXXXX values so this doesn't seem to be a vector table.. or is this binary mapped in 0xea000000?

fifteenhex, 2020-04-21:
The binary is mapped to 0x0. The vector table is at the beginning. The table is made up of ARM instructions instead of jump locations. The first 4 bytes should be the reset vector and that should be a branch to some ARM code that is right after the vector table.

What are you using for disassembly? I'm using hopper v4. I can give you my scrappy hopper database if that helps?

kadamski, 2020-04-21:
Oh, interesting, I though on ARM the vectors contains addresses, not instructions, thats useful, I have to change my reasoning, then.

I'm trying to use ghidra as it is opensource and free. I have some limited radare2 experience but the only real reverse engineering of binaries I did in last 10 years was for the esp8266 at the very beginning of its hype when none of the tools understood xtensa CPUs so all I had was objdump.. So I have a lot to catch up. The hopper has some demo version but since I'm not using such tools too often I wouldn't want to pay for it. But then its not the price of IDA so it would't broke me if its is worth it. Do you find it better for such tasks than Ghidra for example?

fifteenhex, 2020-04-21:
I tried radare2 via the cutter interface and it was a pit painful. Hopper probably isn't as good as IDA as working out all of the control flow etc but I think it was worth the $100.

kadamski, 2020-04-22:
Did you manage to find out what is at 0x1f200800 ?

fifteenhex, 2020-04-22:
According to my notes in the DTS (https://github.com/fifteenhex/linux/blob/4bf698c9b74b02df400bf635b851f85ccf9752ed/arch/arm/boot/dts/chenxing-v7.dtsi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) that's were the mailbox is. I think it's a mailbox between the ARM cpu and a house keeping 8051 that is there to handle deep sleep. The video processing parts also mention a 8051 and in some places openrisc.... so I'm not really sure which of them are in the chip.

kadamski, 2020-04-22:
So basically all the operations on this peripheral are unknown? Od you did manage to find some code  that explains what is done there?

fifteenhex, 2020-04-22:
The vendor code writes the kernel log buffer address into some registers there on start up:
https://github.com/fifteenhex/linux-ssc325/blob/89341c7012404c72e192f198b2ea6405ec80d15d/arch/arm/mach-sstar/infinity3/soc.c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

I'm guessing that's so whatever is behind there is able to write messages in to the kernel log. Other than that I haven't found much other info about it. There are some interrupt numbers that seem to be interrupts from an 8051 to the ARM which might be related.

It's hard to tell though as so much of the code contains vestigial pieces from code for older chips they hacked up. It's possible the registers still exist but nothing is actually connected there.

fifteenhex, 2020-04-23:
I think I see what you where talking about now. I just noticed the bootrom writes to the mailbox box right after disabling the WDT. I guess it's the ARM core telling the PM core that it's alive.

fifteenhex, 2020-04-24:
I thought I might have seen some writes to it in the code that runs in SRAM to do the suspend (https://github.com/fifteenhex/linux-ssc325/blob/89341c7012404c72e192f198b2ea6405ec80d15d/arch/arm/mach-sstar/infinity3/sram.S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) but it looks like I was miss remembering.

I think it is PM related though. The PM code writes the same 0xbabe magic number and then seems to try to turn the ARM core power off via a gpio. My gut feeling is that when it comes back up it writes 0xbabe into the mailbox register to tell whatever is doing the PM not to try waking it up again.

kadamski, 2020-04-24:
In the function that seems to be like a main() (it is called at the end of the reset vector just before endless loop), I can see many writes to this address but this seems like some kind of "checkpoints mechanism" as each write there happens after some operation and the value written is incremented. So first write is 0xb01, then 0xb02 and 0xbff is written at the end of this function and such a call seems to be done before (and sometimes after) important actions and each of them has unique value for the argument. Maybe its just for debugging purposes?

fifteenhex, 2020-04-24:
It's coming back to me now. Yeah, they seem to write a value into a scratch register at different points in the boot rom. I think so they can work out where it died when debugging like you wrote.
Disregard what I wrote about PM. I think I was misremembering.

kadamski, 2020-04-24:
Another unknown peripheral I stumbled opon in bootrom code is at 0x1f28041c and 0x1f28042c. Those registers seems to be writen in the function just before configuring pinmux for NAND/SDIO. Have you stumbled opon those somewhere maybe?

fifteenhex, 2020-04-25:
Looks like that's the "eMMC" copy of the sd host IP block that isn't broken out on the QFN80

https://github.com/fifteenhex/linux/blob/ff5b8260c9748cded793faecb7c3d2590cde928e/arch/arm/boot/dts/infinity.dtsi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

The chip seems to always output E:CD on boot which seems to be about checking the eMMC interface to boot from it but the card detect signal not being low.

kadamski, 2020-04-25:
Looking at the code of the function at 0x1a4, I can see the place where E:CD is printed but there should also be "Load IPL to IMI from eMMC failed! [HALT]\r\n" printed after it. But my understanding of the code might be wrong as I basically cannot see how this string could ever not be printed - it seems like this print was unconditional which is strange. I guess you don't see this message, right?

One thing I'm having problem to understand is that the main function seems to be reading the SPI0_DI pin value to decide what to do next. Then, the unknown to me register 0x1f0070c0 is read and if it is not 0x20 and not 0x4, the value read from DI is overwritten with 1.

Depending on this value, different part of pinctrl is configured. If it is 1, 0xC8 (which you mark as SD/SDIO pull up/strength which would make sense) and 0xA0 (which you did not document), if it is 0, 0xC0 and 0xC4 offsets are used which you documented as NAND drive/pull up (BTW, this means it is for eMMC?). Also least significant bit of 0x4c and 17 least significant bits of the 0x140 offset (which are undocumented) are cleared.

BTW, the offset 0x20 seems to be also little more complicated than you described in pinctrl-mstar.c - in case the value read from DI is 0, bits 0 and 3 are cleared, while bit 2 is set. in case the value from DI is 1, bits 0, 2 and 8 are cleared while bit 3 is set. This chip still has quite some unknowns :)
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
kadamski, 2020-04-26:
I have one additional unknown - the function I mentioned in my previous comment (I'm calling it boot_sd_or_nand() for now) is trying to read one of two PM_GPIO addresses, if the SPI0_DI was 1 (or was forced to 1), it will use 0x1f001f1c, if it was 0 - it reads 0x1f001e1c. So the offset in the PM_GPIO is either 0x11C (SD_CDZ) or 0x1C - this one I don't know, as you don't mention it in gpio-msc313-pm.c. If you have any idea. In both cases, the code will read the bit 4 of the register so it checks the IN value and returns it. If this function returns 1 (so no card present), the "E:CD" is printed.

So if SPI0_DI was 1, this gives us the information if SD card is present and I guess something similar must be there for the other case.. what would that be? eMMC?

fifteenhex, 2020-04-27:
0x1c is PM_GPIO_7 (https://github.com/fifteenhex/linux/blob/6dc9f3186a721550c59820a0a9073034bda8601c/drivers/gpio/gpio-msc313-pm.c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) which isn't physically present on the MSC313E.

I think there might be 3 similar blocks in the chip, "sdio", "emmc" and "nand". I think what you're looking at is probably the code to work out which one to try.

kadamski, 2020-04-27:
> 6dc9f3186a721550c59820a0a9073034bda8601c/drivers/gpio/gpio-msc313-pm.c#L51

This is cool. I was looking at the file in the msc313e branch which has a lot less information about this PM_GPIO offsets. I'll switch to msc313e_dev_v_5_6_rebase instead. I guess this is the branch you are currently working on?

BTW.. Since we don't have datasheet, the only source of the information about the register map is to read the drivers and devicetree. This is spread in many places and is hard to work with. I could spend some time preparing some kind of markdown documentation for the peripherals so that we could have all this in one place. Do you think that would be useful? Would linux-chenxing.org be a good place for that? Would you be willing to review such informations?

fifteenhex, 2020-04-27:
>Do you think that would be useful? Would linux-chenxing.org

I've started doing that now. I'm going to move the register maps out of the drivers in to a page under ip blocks. I've done that for the SAR registers so far.

kadamski, 2020-04-27:
> I've started doing that now

Oh, I didn't notice that. That is something I can help with for sure as I believe you have a lot of other important topics to take care of. I think it might also a good opportunity to spread the knowledge an maybe clarify some things.

fifteenhex, 2020-04-27:
>I'll switch to msc313e_dev_v_5_6_rebase instead.
>I guess this is the branch you are currently working on?

Sorry I should have commented on this last time.. that is my current working branch. That's where all the latest info is so far. I'm rebasing it pretty often at the moment so it's likely to change.

I can add you as a committer to linux-chenxing so you can add anything you find directly if you want?

kadamski, 2020-04-27:
> I can add you as a committer to linux-chenxing so you can add anything you find directly if you want?

I would still prefer you to take a look at what I'm adding there as I'm not yet that confident about some parts. Unless you find it to disturbing to review that, in this case I can commit directly.

fifteenhex, 2020-04-27:
>I would still prefer you to take a look at what I'm adding
>there as I'm not yet that confident about some parts.

That makes two of us. ;)

>Unless you find it to disturbing to review that, in this case I can commit directly.

I don't remind reviewing stuff but the wiki is just a though dump at the moment anyway so I don't think there is any harm just committing direct as you find things.

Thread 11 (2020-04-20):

[TODO] Finish BoM

fifteenhex, 2020-04-20:

kadamski, 2020-04-22:
The tvsarray is something like a SP3051 from little fuse ?

fifteenhex, 2020-04-22:
I went for the cheapest parts I could get from taobao for everything. The part is a no-name generic thing but they list SRV05-4 which is an onsemi part. On a quick glance it looks identical to the SP3051.
On all the boards I've built so far I haven't mounted it.

kadamski, 2020-04-26:
I guess b11b79b941a11807d1c2f3215691a770435c06a1 fixes that, right?

Closed 2020-05-13.

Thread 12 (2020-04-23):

RTS/CTS for serial ports

sbridger, 2020-04-23:
One issue with little router chips (tplink) is that the uarts don't bring out the RTS/CTS handshake lines, which makes serial rather flakey if you are doing any real work with it.
This is needed on one or both of the non-console uarts.

xon/xoff is not especially reliable , measured at 20chars latency in openwrt routers.
(RTS is also needed for RS485 direction)

fifteenhex, 2020-04-23:
The FUART port has RTS/CTS signals. I haven't tried them but the UART is (probably) the well support dw uart.

sbridger, 2020-04-23:
The issue (with routers etc) is: are the pins brought out?
Looks like they are on sch.

BTW I have a serial I2C adaptor unit made for use with little tplink routers. Aside from the main fn, it provides a reliable watchdog and power-down sleep service to the router. OpenWRT on the routers boot pretty fast, so the battery operated units are just turned off for low power. This is also the only absolutely reliable way of regaining control of a locked-up device.

If this is of use to you for a project, you are welcome to one, just ask.

fifteenhex, 2020-04-24:
>The issue (with routers etc) is: are the pins brought out?

They are brought out. I'm not sure if the pinmux code is there to use them yet but I can check.

>BTW I have a serial I2C adaptor unit made

That would be handy. Could you drop me a line via email?

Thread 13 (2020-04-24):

[TODO] Add control for ARM core rail for deep sleep

fifteenhex, 2020-04-24:
pm_gpio4 seems to a magic pin that is used to control the ARM core power rail.

Add a mosfet or something that pm_gpio4 can control to power down the arm core.

Maybe remove pm_gpio4 from the header and put ir_in there instead.

kadamski, 2020-04-24:
Do you have any code reference you could point to which is related to going to sleep?

fifteenhex, 2020-04-25:
The C part is here:
https://github.com/fifteenhex/linux/blob/msc313e_dev_v5_6_rebase/arch/arm/mach-mstar/pm.c

What this basically does is load the assembly part into SRAM and sets a resume address in some registers you'll also see in the boot rom. The boot rom does a check for a magic number and jumps to the resume address back into the kernel.

The assembly part is here:
https://github.com/fifteenhex/linux/blob/msc313e_dev_v5_6_rebase/arch/arm/mach-mstar/suspend-msc313.S

The comments describe what it's doing (mainly ddr self-refresh setup and turning stuff off). The bit I worked out yesterday is right at the bottom. I could never get pm_gpio4 to toggle in my gpio driver.
I worked out that pm_gpio4 is special. The register that is written with 0xbabe locks the pin high so you can't accidently turn the power off from what I can tell.

fifteenhex, 2020-04-25:
Scratch the mosfet bit. Looks like there is something internal that disconnects the power that can be controlled from pm_gpio4.

fifteenhex, 2020-04-26:
Board rework isn't needed. Almost working in software now.

Closed 2020-04-26.

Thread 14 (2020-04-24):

Driver priority and boards?

mbilloo, 2020-04-24:
I'd like to help out with driver work (I have a fair amount of experience working on kernel drivers). What should be priority? Also, do you have any more boards you're giving out/selling?

Thanks

fifteenhex, 2020-04-25:
Right now my priority is to try to get the base machine support into mainline. I want to do this as soon as possible so someone doesn't go and remove the barely used driver for the USB host controller.

Right now I have PCBs left for 4 boards that I'm going to build up and try to send out to people.
I got tons of requests for boards so I might have to be a pretty selfish and send them out to people that would make the most impact before I order the next set of PCBs.

Someone that is really good at thumb assembly that can reverse engineer the DRAM init and add it to the uboot SPL so no blobs are needed to boot is probably the highest priority.

mbilloo, 2020-04-25:
This may be a silly question, but it looks like the bootrom explicitly attempts to load the IPL at a particular address in either SPI NOR or on the SD card. Is the idea that u-boot will simply be at the location of the IPL and so the bootrom will think it's loading IPL but it will instead be loading u-boot (which will do the necessary DRAM setup and rest of the init)?

mbilloo, 2020-04-25:
Also,  where could I find the IPL blob? The linux-chenxing repo doesn't seem to have it.

fifteenhex, 2020-04-25:
> Is the idea that u-boot will simply be at the location of the IPL and so the bootrom will think it's
> loading IPL but it will instead be loading u-boot

Exactly. At the moment because I haven't fully worked out the DRAM setup it is loading the IPL, then uboot's SPL then uboot for real. If we can do the DRAM setup in the SPL we can get rid of the IPL and everything is opensource. The current uboot source already has an option for building the SPL with the right header for the bootrom to think it's an IPL.

The current IPL is here: https://github.com/breadbee/breadbee_buildroot/blob/master/br2breadbee/blobs/IPL.bin

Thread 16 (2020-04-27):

[QUESTION] Some UART related questions

kadamski, 2020-04-27:
The UART seems to be mostly compatible with DesignWare UART. The best document explaining register map of this peripheral I was able to find is the https://linux-sunxi.org/images/d/d2/Dw_apb_uart_db.pdf, do you have anything better?

Based on this document, I cannot really understand what is happening in the BootROM so either I have wrong document or..

The code seems to be, for example, writing to register 0x18 which should be MSR which is read-only? What is 0x20 and 0x38? The code also writes 0x14 to 0x00 which is supposed to be THR but this is not any sensible character.. Would that be a pattern to detect the baudrate?

fifteenhex, 2020-04-28:
As far as I can tell the UART is a DW one with one of the registers moved. I added a fixup for the register location to the linux driver.

I think the issue with the addresses you are seeing are because the registers are shifted because of how they are connected to the bus. The shift is 3. So the register offsets are 0, 0x8, 0x18,...

kadamski, 2020-04-28:
Oh, I have to take a look at this fixup, then. And the shift is probably what I was missing. Those tty drivers in the kernel are always hard for me to wrap my head around as there is so much abstraction there :)

fifteenhex, 2020-04-28:
Another thing to look out for is that the register locations are always 2 bytes 4 bytes apart for stuff that's connected via the "RIU". So with blocks like the ethernet and usb that are existing designs and have 32bit registers those registers are split over 8 bytes. It's pretty strange but I think it's maybe because they used the same designs in their TV chips that are driven by some sort of 16 bit 8051 thingy.

kadamski, 2020-04-28:
Yes, generally there is a lot of registers which internally only have 16 bits but take 32 bits. And even though they could be packed into one 32bit register, they are split into H and L 16bit register. Like the peripheral was designed for 16bit CPU.

But back to the UART, I feel a little stupid I did not notice that. I assumed the shift was 4, not 8. When applying shift=8, not all of the registers does make sense. I can see the code setting divisor to 320 which for 12Mhz clock gives nice 38400 baud rate as expected. I can see the 8N1 mode being set, fifos being enabled and reset... all that stuff. The only unknown register is at offset 0x80 (so its is 0x14 before shift). Least significant bit of this register is zeroed as the first operation of the function configuring UART. Any idea what could that be?

Also, as a last action, an yet another unknown pinctrl register (offset 0x14c) is written value 0x3012. Again, no idea what this does but appartenly it must be something related to UART.

fifteenhex, 2020-04-28:
>The only unknown register is at offset 0x70 (so its is 14 before shift).
>Least significant bit of this register is zeroed as the first operation of the function configuring UART. >Any idea what could that be?

That seems to be after the standard registers. I'm guessing it's something to do with the DMA feature.

>Also, as a last action, an yet another unknown pinctrl register (offset 0x14c)
>is written value 0x3012. Again, no idea what this does but appartenly it must
>be something related to UART.

0x14c is called "uart sel". It seems to be for selecting which UART is behind the pins. It seems like it's even possible to connect the pm mcu (if there really is one..) to the UART as well.

```
//#define REG_UART_MODE          0x1F203C0C
//#define REG_UART_SEL           0x1F203D4C
//#define REG_UART_SEL4          0x1F203D50
#define REG_FORCE_RX_DISABLE   0x1F203D5C
```

Closed 2020-05-03.

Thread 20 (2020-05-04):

[QUESTION] Power related questions

kadamski, 2020-05-04:
I've noticed that the MSC313e data brief mentions 0.9V as the typical Core Power Supply Voltage  (while 0.87 is minimal, so quite close). You are using 1.0V, however, which seems to be fine since it is much lower than the absolute maximum (1.26V) and the timing diagrams in the brief also mentions 1.0V/0.9V as VDD. So I was wondering - did you choose 1.0V just to be on a safe side? Maybe this is the reason why, even though the CPU is rated to 800Mhz, you can easily overclock it to 1GHz? Maybe with 0.9V that wouldn't be possible?

Also, I wanted to understand the role of R21, R22 and R18. Why aren't the two resistors creating a  voltage divider enough there?

fifteenhex, 2020-05-05:
I went for 1v as I didn't have a reference schematic and that's what I measured on an existing product. I think I have an cpufreq table with the *right* core voltages for different frequencies now.

The E version of the part runs fine a 1GHz. 1.2GHz works as well but other parts of the chip don't like it and eventually the CPU gets stuck on a bus access from what I remember. The older non-E version only runs at 800MHz and gets stuck when it tries to ramp up to 1GHz even with 1V core supply.

R21, R22 and R18 were intended to add extra load if the load presented by the soc wasn't enough for the ea3036c as I had issues with that with the first 2 layer incarnation. The 100k value doesn't mean much. I'll probably get rid of them at some point to make space.

kadamski, 2020-05-05:
So the SoC has capability to change the core voltage to get smaller power consumption / heat generation internally based on this 1V input voltage? Meaning the actual value does not matter that much..

fifteenhex, 2020-05-05:
The regulator needs change the core voltage to save power. I think that could be done with a resistor and one of the gpios to change the feedback for the core voltage buck converter.

kadamski, 2020-05-05:
But there is not much to be gained if we cannot really go below 0.9V, right?

fifteenhex, 2020-05-05:
I don't think so. In sleep with the memory in self refresh is seems it'll be around 25mA.
To get much less I think the DDR would need to be turned off completely and that means adding a real PMIC really.

kadamski, 2020-05-05:
The DDR in self refresh mode could be powered differently than in normal mode?

fifteenhex, 2020-05-06:
mm not sure about that. Without knowing what DDR chip is actually in there it's hard to know if it'll like the DDR voltage changing or not.

Closed 2020-05-19.

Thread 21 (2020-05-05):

MUSB USB device controller?

mbilloo, 2020-05-05:
@fifteenhex since @kadamski is working on the crypto engine, I thought I could tackle the USB controller, unless you had something else with higher priority?

fifteenhex, 2020-05-10:
Sorry for the delay.

Getting the usb host controller working would be awesome. The only thing I can think of right now aside from that that I really want is an SD controller driver in u-boot.

You'll need some hardware to work on that I think. Right now I can't get hold of some of the parts I need to build up more boards but I can buy you a dash camera that has another chip in there that is almost identical for you to hack on. I've been using one for a lot of the reverse engineering as it's a bit easier to unbrick.

mbilloo, 2020-05-10:
That would be awesome. Just send me the link and I can order it myself
(that may be quicker).

On Sun, May 10, 2020, 9:38 AM Daniel Palmer <notifications@github.com>
wrote:

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

fifteenhex, 2020-05-11:
The 70mai lite is the best thing I can find at the moment. If you crack it open you get easy access to the serial port and a button to trigger booting from SD. Also the usb charge connector has the USB data singles wired to it so it should be usable for testing the usb host controller.

It's about $50:
https://www.gearbest.com/car-dvr/pp_3006867820113255.html

mbilloo, 2020-05-13:
I ordered the dash cam and am waiting for it to come in. Could you send a photo outlining the location of the serial port ? I imagine that it's TTL output, correct?

Thanks

fifteenhex, 2020-05-13:
I don't have mine to hand at the moment otherwise I'd send a photo but if you look here: https://fccid.io/2AOK9-MIDRIVED08/Internal-Photos/internal-photos-4351132.pdf
The page labelled 5 of 8 has a photo of the guts. The pads between the two push switches on the bottom corner are the UART. GND RX TX 3.3V from left to right if I'm remembering correctly.
The button on the left side forces it to boot from SD card.
It's 3.3V logic so you'll need a USB to serial that uses 3.3v levels like the cp2102 ones.

kadamski, 2020-05-14:
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

TX RX GND 3.3V

mbilloo, 2020-05-19:
Since it looks like the SD card driver works on the mercury5 (since I can boot off of the SD card), do you want me to move to the USB controller kernel driver?

fifteenhex, 2020-05-19:
At the moment u-boot itself can't load from SD. In the rtk file u-boot and the kernel are joined together to trick the IPL into loading both into memory.

Once I have the u-boot SPL working properly an SD driver will be needed to load the full u-boot as the SPL will be running the show. I plan on porting the kernel driver I wrote to u-boot at some point. If you wanted to take a look at that before I get to it I wouldn't stop you... ;)

The USB controller is probably more interesting though. I think it'll just need the musb glue bit implementing properly and maybe some changes to the phy/mux part to connect the port to the controller. I started on it here: https://github.com/fifteenhex/linux/commit/6f5a574163a42ce7617c846ea981f269c49c5449
The registers and bit meanings for the MUSB controller are listed in the msb2521.pdf datasheet so there is something to actually work from.

Once that works you could make the mercury5 camera into a usb ethernet gadget and getting stuff in and out of it would be a bit easier.

fifteenhex, 2020-05-22:
FYI: u-boot sd driver is in progress.

mbilloo, 2020-05-22:
Great! I'm balancing my day-time job and this effort. I'll keep you posted
as I make progress on the USB controller driver.

On Fri, May 22, 2020 at 8:24 AM Daniel Palmer <notifications@github.com>
wrote:

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

--
Mohammed Billoo

fifteenhex, 2020-05-23:
Please feel free to work at your leisure. Also please drop me a line if you want to be reimbursed for the cost of the camera. Also please leave a comment here https://github.com/breadbee/breadbee/issues/25 so I can keep track of allocating dev boards. :)

Anyhow, the driver is pretty rough but u-boot can see sd cards now:

```
field write, off 30, mask 2, shift 1, value 0, masked value 0
field write, off 30, mask 1, shift 0, value 0, masked value 0
field write, off 30, mask 100, shift 8, value 0, masked value 0
                MMC_RSP_R1,5,6,7         0x00000920
=> mmc info
mstar_mmc_getcd:492
Device: MSC
Manufacturer ID: 5d
OEM: 5342
Name: N1BN1
Bus Speed: 25000000
Mode: SD Legacy
Rd Block Len: 512
SD version 1.0
High Capacity: No
Capacity: 1.9 GiB
Bus Width: 4-bit
Erase Group Size: 512 Bytes
```
I think this will make life a lot easier working on the camera. I'll add some notes on using it to the breadbee_dev page at some point.

mbilloo, 2020-06-06:
"musb_am335x.c" referenced in https://github.com/fifteenhex/linux/commit/6f5a574163a42ce7617c846ea981f269c49c5449 doesn't exist. https://github.com/fifteenhex/linux/commit/4baa550ecc86693106493bd92382e0edb8caf64d says to drop the dummy driver, but it looks like your commit added the inclusion of the driver back in, but not the source itself. What am I missing?

fifteenhex, 2020-06-07:
That's going to be a rebase fail on my part. I probably merged those lines back in when they got dropped from mainline and a I rebased. You can take them out.

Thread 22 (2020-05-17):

Flashing u-boot?

mbilloo, 2020-05-17:
Got the dashcam, connected UART, and didn't blow anything up. Are there instructions on flashing uboot?

mbilloo, 2020-05-17:
It looks like instructions are in the breadbee_dev and buildroot repos. However, when I boot, I don't have the standard u-boot shell, it looks like something else. How can I get to u-boot?

Thanks

fifteenhex, 2020-05-18:
Sorry, for some reason I didn't get a notification.

With the mercury5 chips booting directly from SD works. On that camera you can disconnect the battery and then press the button closest to the battery connect while plugging in the usb to get it to boot from SD. I've made an SD card with the right format with u-boot and a kernel here: https://drive.google.com/file/d/1xbFF7_SD8Ws4wTvUJUDp8DqNqJAbw0-C/view

Some notes on how to boot the kernel there are here: https://github.com/breadbee/breadbee_dev#booting-the-uboot--kernel-fit-rtk-image

I'll try to put together some better documentation for how to do u-boot/kernel hacking using the camera.

mbilloo, 2020-05-18:
Do you want me to do that as I progress? I can update the README to point to the appropriate links as I move along and submit a PR once I'm done. This way, if there are any gaps in the documentation, I can do it right away instead of you having to search through this exchanges later on.

fifteenhex, 2020-05-19:
I'll clean up the dev repo a little bit and we can go from there. The plan was to make it possible to check that out, run a script and start hacking but I never got around to it. I'll try to fix that in the next few hours.

fifteenhex, 2020-05-19:
I've updated the breadbee_dev repo with just enough to build the "rtk" image for doing u-boot/kernel work on the mercury5.

My workflow at the moment is to tweak stuff in the kernel or u-boot, build the rtk and copy it to SD card. It's not as nice as booting from tftp.. usb ethernet does work on the m5 once the kernel is loaded so it's possible to replace the rtk file from linux if that makes things quicker.

mbilloo, 2020-06-06:
@fifteenhex - cool! Instructions work.

"usb ethernet does work on the m5 once the kernel is loaded..." - Doesn't the driver for the USB controller need to be working to support USB ethernet?

mbilloo, 2020-06-06:
Never mind, it looks like the driver already supports host mode (hence the support for Ethernet over USB), but not in device mode, hence the issue. I'll move this conversation over to that issue.

Closed 2020-06-06.

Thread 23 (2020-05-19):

[TODO] Pay someone to do "production ready" layout fixes.

fifteenhex, 2020-05-19:

bencorrado, 2020-06-25:
Do you have a list of asks here or just have someone review then make changes based on the review.  I could potentially help here and would not be looking for a few.

fifteenhex, 2020-06-25:
A review by a proper EE or just someone that knows what they are doing would be great. I just tinker so going ahead and trying to make 2000+ of these scares me a little. ;)
Things that I know are certainly wrong are things like the routing of the USB signals. I didn't think I'd ever get the software side of the USB working so I just crammed them in instead of trying to route them as a proper pair.

kadamski, 2020-06-25:
You mean the USB signals on the 1mm header? Fortunately, the board is small itself so the effect of those traces is not that big. The bandwidth of the USB signal is ~90Mhz which means a wavelength of ~170cm. So the 1/10 of that is 17cm which is way more than the 30mm the dp/dm signals on the breadbee have. The two lines are not matched in size but the skew is 30.385 - 28.869 = 1.5 mm out of 45mm allowed (this includes the skew in cable as well, of course but still there is a large margin). Kicad do have an easy way to control match the length of the two wire pairs so this could be easily improved. The biggest problem is, probably, the fact that you are going over vias and especially dp has this sharp angle. Also the fact that headers are used is not without effect, I guess.

The only other thing to think of is the impedance of the pair which should be 90 ohm. This is controled by the track width and depend on the spacing between lines (6 mils in your case?), the material of between the layer the trace is going and the first inner layer and the high of the dielectric between them. JLCPCB has a nice calculator you can use to calculate the width of the trace for their 4 layer boards on https://cart.jlcpcb.com/impedanceCalculation. So for example for their normal board (1.6mm thick) you should be using 9 mils (0.22mm) trace width wich is a little more than you have now (for the current 0.15mm width you will get ~105 ohm of differential impedance with 6 mils spacing) or you would have to reduce the spacing between traces to 4 mils which would give you ~95 ohms.

Of cource the problem of calculating the impedance is that it depends on the dielectric that is used between the layers (the type and the height) so you would first need to decide where you are going to manufacture the boards (we know it's not in JLCPCB, right? ;)).

The good document describing this is https://www.silabs.com/documents/public/application-notes/an0046-efm32-usb-hardware-design-guidelines.pdf. But, well, as you said, a look from a proper EE would probably be even better :)

kadamski, 2020-06-25:
Oh, I forgot to check the actual inner layer adjacent to the traces (In2.Cu) - it is not solid (you trace some power lines there :/) and there are a lot of voids in it above the wires which is bad as it dos not make a good return path for signal. This may be the biggest problem.

The oscillator is far away so this should not be a problem but the traces are going very near of the inductors used by ea3036 which is a switching mode regulator and this should be avoided. Also they are going near SPI traces which might be considered high speed signals as well (what is the max frequency of those SPI lines - 25Mhz?) so it would best be avoided too.

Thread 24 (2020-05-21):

[QUESTION] Boot from SDIO / SD CARD Interface

kjngineering, 2020-05-21:
Hi fifteenhex,

Looks like a really interesting mcu - I might actually have some application for me. The dual SPI busses makes it very interesting!

Based on your current understanding of the chip, do you think it is possible to have it jump to a SPL that is in a region of an SD Card (ala Allwinner) as opposed to SPI NOR flash?

Assuming this is possible would this allow you access two the two SPI busses for devices?

Thanks

fifteenhex, 2020-05-22:
From what I can tell the bootrom can't boot from the SD controller that is broken out on the msc313e chip so you have to have something on SPI NOR to boot.
I intend on porting the kernel driver for the SD controller to u-boot so u-boots SPL can load everything else from SD which would mean you could probably use an 8 megabit/1 megabyte flash.

If you just need two SPI buses then you can already do that as there are two SPI controllers aside from the memory mapped one for SPI NOR.

fifteenhex, 2020-05-24:
FYI: The uboot port now has some clunky sd support that is enough to load the kernel from SD.
You still need some SPI-NOR but 1MB is enough for uboot.

Closed 2020-11-29.

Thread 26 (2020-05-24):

Mainlining effort

kadamski, 2020-05-24:
I've seen you have posted first few patches to the mainline but the effort seems to be stuck for now. I guess, you have a lot of other work and I know mainlining anything requires quite some time. Is this something you would like to be helped with or this is something you would like to do yourself?

I feel like I could help out with that, once I've got a board to test the code on.. The M5 in dashcam, if I remember correctly, is not suitable for that?

fifteenhex, 2020-05-24:
TL;DR; version - I'd like help but at the moment my tree is a bit of a mess. Working on something like the aesdma that I'm not poking at right now might be easier because I won't be constantly breaking your stuff with rebasing...

Longer version;

I have a patch set that I think I can clean up and try pushing again but I haven't gotten around to finishing up the cleaning up part. Splitting out all of the device tree changes and moving them into the commits they belong with is a major pain (basically merging all the dt commits into a jumbo commit, moving it before the other commits, splitting it back out again.. )

The M5 is suitable for mainlining work I think. One of the big changes between the current code and the first version I pushed is that the current stuff should work with almost any chip in the family whereas the first attempt would have only worked with the msc313e. We should be able to push an initial patch that adds support for the msc313(e) and the m5 chips in one go.

Once I have the memory init and sd card driver stuff ported from the m5 build to the breadbee build of u-boot I'm going to get back onto mainlining. I really want to get initial support in before the first run of boards is made. Once the initial bits are in getting the clock support etc is going to be a big undertaking and it would be good to maybe give you the clock stuff to push, someone else the pinctrl stuff etc

kadamski, 2020-05-24:
> Splitting out all of the device tree changes and moving them into the commits they belong with is a major pain (basically merging all the dt commits into a jumbo commit, moving it before the other commits, splitting it back out again.. )

Seems like a work I do a lot daily so, well, I don't feel like it is a pain to me to do such thing so we could cooperate somehow on that if you like.

fifteenhex, 2020-05-29:
I'll have a think about how we can do it effectively. I probably need to clean up my work branch a bit, update the "for mainline" branch and then we can clean up all of the checkpatch etc errors and push it.

fifteenhex, 2020-06-09:
Planning to drop a patch set for the initial support into the 5.8 release cycle.

Work will be happening here: https://github.com/fifteenhex/linux/tree/msc313_mainlining

kadamski, 2020-06-09:
@fifteenhex cool. If you could CC me when you are going to push something, that would be great.

fifteenhex, 2020-06-09:
The commits I'm going to push are in place now. If it goes in it'll be the bare minimum for a shell from an initramfs on both the breadbee and the m5 camera.
If you could take a look and see if you notice anything stupid that would be really helpful.

Planning to run checkpatch etc tomorrow and send it out after that.

kadamski, 2020-06-10:
@fifteenhex there's not much of the code to look at yet. I was only able to point out some cosmetic issues so far. What I would like to do, but I'm not sure I will have time for this today, is to actually boot the camera board from this kernel.

fifteenhex, 2020-06-10:
Thanks for taking a look. The first set of patches has been pushed. Hopefully we can get those in for 5.8.

I think the next thing we should try if/when that set goes in is add the parts that are purely device tree based like reset support and the internal sram. Those would be an easy "get something in mainline" win so I'd like to hand them over to someone that wants to give it a try.

fifteenhex, 2020-07-25:
Update on this: Initial patches have been merged into an upstream branch so should eventually make it into mainline.

stappersg, 2020-07-25:
> patches have been merged into an upstream branch

What is the URL of _an upstream branch_?

fifteenhex, 2020-07-25:
https://git.kernel.org/pub/scm/linux/kernel/git/soc/soc.git/log/?h=arm/newsoc

The patches are right near the top at the moment.

fifteenhex, 2020-08-04:
Update: the initial patches entered Linus' tree today so should be in 5.9

Closed 2020-11-29.

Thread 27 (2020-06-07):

MK5P USB connector sucks.

fifteenhex, 2020-06-07:
Find a connector that has through board lugs that has a generic version.

kadamski, 2020-06-26:
I've went trough different boards I have to see how they handle that and indeed most of them use microusb connector with a trough-hole soldered lugs. The bluepill boards I have are a notable exception, however, as they are soldered with single SMD pads only on both sides (like MK5P) and the only difference is they seem to have small plastic lugs going to the other side.
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
The only way to peal it off the board was to use leverage of the microusb cable connector. This type of connector requires much less space on the bottom layer compared to the trough hole lugs.

When I tried to pill of the connectors on my nodemcu boards which have 4 trough hole lugs, it was much much harder though, to the point I was worried I would actually damage the cable connector.

Looking at the board, however, I think it wouldn't be much of a problem to fit those through hole pads for the microusb cable but the question is how will this influence the manufacturing process. Maybe it would be best to work this out with the manufacturer and pay less attention to the wide availability of the connectors?

One more thing to note, however, is that the ETH jack is also SMD mounted only. The mounting pads are larger but the connector is too so it is much easier to use leverage on it.. if microusb is easy to peel off, wouldn't ethernet jack be susceptible to that too?

One last thing is the soldering process - maybe the reason why it wasn't that easy to peel off the connector on bluepill was because it was soldered with a high temp no lead solder while you are using low temp solder paste? Did you try to use normal solder and an iron just for the side pads of the connector to give it a little more strength?

fifteenhex, 2020-06-26:
I think it was probably the batch of connectors I had. I tried pulling the same style of connector off of some older prototypes I made and it took a lot of force to pull them off and the pads came off with the connector. The ones I used recently leave the solder intact and the underside doesn't look like the solder wetted to it.

moqmar, 2021-04-25:
What about a USB Type C version of the board? The [Molex 2171790001](https://www.molex.com/pdm_docs/sd/2171790001_sd.pdf) looks a bit stronger as the shield pins are soldered *and* go a bit into the board, and is relatively cheap. The [JAE DX07S016JA1](https://www.jae.com/en/releases/detail/id=92529) would additionally have plastic pins, but is a bit more expensive.

fifteenhex, 2021-04-27:
Going through the board is a bit of no go at the moment as it would break the routing.
I think the 16 pin USB-C connectors would be the way to go. I'm going to use one on the SSD210 board I'm working on.

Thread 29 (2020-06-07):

Powering the dascham + USB ethernet

mbilloo, 2020-06-07:
@fifteenhex , my strategy for powering the dashcam and having USB (initially for Ethernet) was to use an external power supply instead of the battery and use a spliced micro USB cable that doesn't have power coming out to the USB ethernet adapter. That would be provided by another spliced cable. See attached diagram.
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

Was that were you doing to test USB? I imagine the USB port on the dashcam is meant to power the dashcam and charge the battery (instead of providing power to an external device)

fifteenhex, 2020-06-08:
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

This is how I've been doing it. I attached a cheap USB A breakout to the internal pads for the port and then use the supplied USB cable to power it. The supplied cable doesn't have data lines so it works perfectly for supplying 5v and not messing with the data lines.

Closed 2020-11-29.

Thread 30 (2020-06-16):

Rethink "timing" capacitors

kadamski, 2020-06-16:
The board has a few RC circuits used for power-up timing. The sequence seems to be:
a) the EN1/2 of EA3036C should start first (for 3.3 and 1.8V), they need some time to stabilize
b) the EN3  of EA3036C should go at least 1ms after that (to get 1.0V VDD)
c) the reset pin should not go low (~1.3V) for at least 5ms

To achieve that, a 1uF capacitor and 1M (a), 1.1M (b) and 1.2M (c) Ohm resistors are used. I see two problems with that:
1. The typical tolerance of the cheap resistors are 5%. 1% are not much more expensive so they could be used instead. However the typical tolerance of the capacitors is 10% (or even 15%) and getting more accurate isn't that easy/cheap. With bad luck, 1M*1.1 is bigger than 1.1M*0.9 and this could cause trouble. To solve this, the resistor value differences could be bigger.
2. The datasheet of EA3036C is suggesting using 100K resistor which is an order of magnitude smaller. Since those resistors are also acting as pull-ups after reset sequence, it might make a difference (10M might be to weak pull-up?). Similarly the msc316 databrief seems to be suggesting 10k for reset pull down which is 2 orders of magnitude smaller.

While smaller pull-up/down resistors increase the power consumption, with 100k or even 10k we are still talking microamps here while the SoC itself consumes tens of milliamps so this should not be a big deal, I think. The design does already use some 100k/150k/200k resistors and 100nF capacitors so changing to those walues will also shorter the BoM list as well making assembly slightly cheaper.

fifteenhex, 2020-08-11:
From @wtarreau

So regarding the resistors choices, here's what I can propose:
  - use 300k, 680k, 1000k for en1+en2, en3, cpu_reset
    => that really cuts the en1/en2 time to 1/3, hoping it's still
       enough.

  - replace all 100k bleeding resistors with 150k

  - readjust divider values accordingly.

With this I can reduce the BOM from 11 resistor values to 7:

   R1,R19,R20 = 300k
   R2,R6,R18,R21,R22 = 150k
   R3,R5,R7 = 680k
   R4,R8,R23 = 1000k
   R9,R10 = 390
   R11,R12,R17 = 0
   R13,R14,R15,R16 = 22

This gives the following voltages:
  1.0V => 0.6*(1+680/1000) = 1.008
  1.8V => 0.6*(1+300/150) = 1.800
  3.3V => 0.6*(1+680/150) = 3.32

wtarreau, 2020-09-19:
Hey Daniel, just an update on this, I've just assembled my 3rd board using the resistor values above and it works fine, so I guess the values can be updated to ease component sourcing by end users.

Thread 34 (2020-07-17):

[TODO] New version with SSC325 instead?

fifteenhex, 2020-07-17:
The upgrade to the MSC313E seems to be the SSC325. They are currently ~$1.80 on the market which is better than the $3.40 best price I have for the MSC313E. The SSC325 has 88 pins though so it might not fit.

kadamski, 2020-07-21:
How about its availability? Can it be bought in single quantities?

fifteenhex, 2020-07-21:
I don't think I can get singles at $1.8 each but I can get 100 at that price apparently.
Trying to find a reasonable pin out before buying 100 of them though. :)

fifteenhex, 2020-07-29:
I found a broker that had them for $1.50 each so I bought 100.

assa31, 2020-08-03:
Did you find a pinout for this chip?

fifteenhex, 2020-08-04:
> Did you find a pinout for this chip?

I have a partial pinout and it seems it's probably pin compatible with the msc313dc that I have a databrief for.

assa31, 2020-08-04:
> > Did you find a pinout for this chip?
>
> I have a partial pinout and it seems it's probably pin compatible with the msc313dc that I have a databrief for.

Could you please share your databrief?

fifteenhex, 2020-08-04:
Databrief for the MSC313DC is here: http://linux-chenxing.org/infinity3/msc316dc_pb_v03.pdf
The pinout of the SSC325 I have part of (part of a screenshot of a schematic) matches up so it's probably mostly the same.

assa31, 2020-08-04:
> Databrief for the MSC313DC is here: http://linux-chenxing.org/infinity3/msc316dc_pb_v03.pdf
> The pinout of the SSC325 I have part of (part of a screenshot of a schematic) matches up so it's probably mostly the same.

Thank you, do you perhaps know what baud rate these chips work at? And if pin 22 and 23 ate the debugging pins?

fifteenhex, 2020-08-04:
22 and 23 are the pm uart pins which is usually used for the u-boot console etc. The normal baud rate for those is 115200.

assa31, 2020-08-19:
Does anyone know what cross-compiler the mstar uses?

fifteenhex, 2020-08-19:
If you boot one of their kernels and take a look at the kernel version string it should show what toolchain they built it with.

BTW: this isn't really the place to dig for general MStar/SigmaStar information. Especially about their SDK etc as the intention is not to use any of their code as it's total garbage.. you can look for yourself as people have uploaded them to github. Maybe for general information take a look at the linux-chenxing site I made (http://linux-chenxing.org/).

assa31, 2020-10-09:
Hi, I'm busy working on one of their camera modules. I managed to get the toolchain and build a kernel. but when I run their load ko file then I get the error unknown symbol. do you maybe know of a solution or of other camera libraries that I can use?

fifteenhex, 2020-10-09:
@assa31

Sorry this issue isn't a support area. Please stop asking unrelated questions here.

fifteenhex, 2020-11-29:
Another reason to do this:

The SSC325 can apparently deep sleep at ~3uA.

iamdavidcz, 2021-04-16:
@fifteenhex
I have managed to create a simple schematics of the possible candidate for the second version of Breadbee. I would like to integrate the following components on the 32 x 32 mm board:
1. SigmaStar SSC325 (rather obvious)
2. Ampak AP6256 (2.4/5 GHz dual band 802.11ac chip)
3. Winbond W25N01GVZEIG (1Gbit SPI NAND Flash)
4. EA3036C (3-channel power management IC).

Certainly, there are many mistakes and faults in this schematics considering my little experience in designing PCBs, but I would like to share what I have already achieved. Could you create a new **breadbee2** repo and give me push access to it so others could contribute too?

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

fifteenhex, 2021-04-16:
Hi @iamdavidcz

I just notice I got an email from you a few days ago.. sorry for not replying yet..

Anyhow the SSC325 version of the BreadBee is/was going to be called the SuperBreadBee.
I created a repo for it a long time ago but never pushed what I had. https://github.com/breadbee/superbreadbee
For now I have made a repo for you here: https://github.com/breadbee/wip_bb2

Maybe we can make this the superbreadbee at some point.

iamdavidcz, 2021-04-16:
@fifteenhex Thanks, I will push my KiCad files to **wip_bb2** repo for now.

iamdavidcz, 2021-05-03:
Hi @fifteenhex,
I have sent you a repo with KiCad project for a new Breadbee.
Please take a look when you get a minute.

fifteenhex, 2021-05-03:
Hi @iamdavidcz

I'm going to take a look tomorrow. If I don't spot anything obvious I'll make an order on oshpark.

iamdavidcz, 2021-05-09:
Hi @fifteenhex,
Did you get a chance to look into my design files?

fifteenhex, 2021-05-10:
Hi @iamdavidcz

Sorry I got pretty sick over the weekend and didn't get around to looking at it. I'll try to take a look tomorrow.

iamdavidcz, 2021-05-10:
@fifteenhex
There's no hurry, I hope you feel better now :)

dasfdlinux, 2021-08-11:
@iamdavidcz
I don't see your design files on the wip_bb2 or superbreadbee repos anywhere. Do you have them on one of these repos that I can checkout and take a look at? I'm curious about the project, and was thinking about looking into the future version of the hardware.

iamdavidcz, 2021-08-19:
@dasfdlinux
They are located [here](https://git.iamdavid.cz/breadbee2/).

@fifteenhex
Feel free to push them to wip_bb2 repo :)

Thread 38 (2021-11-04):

2 microphones through ALSA (assuming working on-board audio codec)

dumblob, 2021-11-04:
Just discovered this very nice SoM which is one of the closest to what I'm looking for.

I'm interested in Linux (incl. ALSA) capable as-small-as-possible board with an integrated (on-board or in SoC/SoM) audio codec which supports two microphones.

Does this board offer 2 mics? Does the ALSA support already exists for the codec?

If not, do you know of some other very small Linux-capable (64MByte RAM is enough) SoM or PCB with integrated codec for 2 microphones?

----

Btw. I'm planning to use micro SD card to boot from. As a nice to have would be support for battery power supply and an LTE (I need full speed and not LTE-M) shield. But that's lower priority than two mics working with ALSA out of the box.

HeinzAlberto, 2021-11-04:
Hi there!

I'm sorry but I don't think that you'd be able to connect 2 mics. The SoC has one ADC for a mic (as well as an DAC for mono line out).
Anyway, there are other interfaces. Guess you could use SPI (some MEMS support it) or go over the USB 2.0 host interface and use a external sound chip...

- Hope that helps you!

Btw.: SD-Boot ist supported by the SoC

HeinzAlberto, 2021-11-04:
(If you're willing to code a bit more you can also check out the recent ESP32-variants. If the are able to do multi-mic VoIP-Calls woth active noise-cancelling, it might also be able to solve your problem ;-) )

dumblob, 2021-11-04:
Thanks for clarification about the number of ADCs. USB is a bit off for my use case due to high power consumption. But it'd be the easiest solution, that's for sure.

> (If you're willing to code a bit more you can also check out the recent ESP32-variants. If the are able to do multi-mic VoIP-Calls woth active noise-cancelling, it might also be able to solve your problem ;-) )

I need to use opus to achieve the highest quality while maintaining acceptably low bitrate. So if modern ESP32 is capable of encoding to Opus in near-realtime (1 second delay would be acceptable), then I'd consider writing more code and go that route instead of fully Linux-capable SBC/SoM. But I slightly doubt it's fast enough (considering also the limited RAM options I saw with ESP32 boards).

I'll continue with the hunt then. Thanks anyway!

(actually I'm getting a bit desperate, so NDA will probably also be an option - IDK yet)

dumblob, 2021-11-04:
Oh, btw. I don't have any experience with MEMS mics especially when it comes to their quality. Do you think they offer good quality say even for some occasional all-around music recording (not just speech)?

HeinzAlberto, 2021-11-05:
I don't knoe how they perform with really low frequencies but in general there are many MEMS out there with good quality. Okay, every Smartphone has one nowadays but speaking from e.g. my 2019 semi-professional camcorder, it has a MEMS too (and it sounds great, even on concerts).
Of course you can't really compare it to these ECMs RØDE uses but compared to typical ECMs I would consider MEMs at least "good as". (And they have a higher SNR.)

fifteenhex, 2021-11-05:
I think the biggest roadblock here would be that the audio part of these chips isn't worked out yet.
The SSD201/SSD202D apparently support 4 dmics but that's not much use without an ALSA driver.

dumblob, 2021-11-07:
> I don't know how they perform with really low frequencies but in general there are many MEMS out there with good quality. Okay, every Smartphone has one nowadays but speaking from e.g. my 2019 semi-professional camcorder, it has a MEMS too (and it sounds great, even on concerts). Of course you can't really compare it to these ECMs RØDE uses but compared to typical ECMs I would consider MEMs at least "good as". (And they have a higher SNR.)

I need to buy some of the best ones and try - internet seems generally positive about the development of MEMS mics (mainly driven by smartphones).

> I think the biggest roadblock here would be that the audio part of these chips isn't worked out yet. The SSD201/SSD202D apparently support 4 dmics but that's not much use without an ALSA driver.

Yep, that'd be the biggest roadblock. Basically I wanted to avoid developing yet another shield with an audio codec. I've done that once (PCB, DTB, and quite extensive driver "glue" as there was some generic driver just for the codec) but for a second version of the system I just thought why not to stick with an existing platform. Apparently it's not that easy to find such platform :wink:.

dumblob, 2021-11-08:
> It's moving away from the breadbee, but about an RPi Zero? It should have enough power by far to drive serveal mics, it has good documented hard- and software. (If thats not to expansive)

Yep, that'd be totally fine if I wasn't this much constrained by physical dimensions. Breadbee is less than half the size.

HeinzAlberto, 2021-11-08:
Than I could offer VoCore or, a bit bigger, NanoPi Neo

dumblob, 2021-11-08:
>Than I could offer VoCore or, a bit bigger, NanoPi Neo

I'm in contact with VoCore guys - they said it's possible but not out-of-box prepared for 2 mics (non-MEMS). But if the work would be upstreamable, I'd consider it - I just didn't get any clear answer whether they would accept such patches and if it's even possible to make the patches "backwards" compatible (i.e. without disturbing anything in the existing ecosystem).

NanoPi Neo should be acceptable if used with strict low-power settings (almost everything turned off and CPU quite heavily underclocked) but I'd need to de-solder the USB & ETH connectors (in case of breadbee there seemed to be a choice to just "leave the ETH connector out" during pick & place).

fifteenhex, 2021-11-09:
@dumblob

There are some very small and cheap ($10) SSD202D modules out there. That would give you 2 x cortex A7 and 128MB of RAM and apparently support for multiple dmics. If you know audio stuff maybe you could help me writing a driver for the audio hardware?

dumblob, 2021-11-09:
> There are some very small and cheap ($10) SSD202D modules out there. That would give you 2 x cortex A7 and 128MB of RAM and apparently support for multiple dmics.

Yep, that's more or less why I considered breadbee in the first place :wink:.

>If you know audio stuff maybe you could help me writing a driver for the audio hardware?

I wouldn't say I know audio stuff - it was anything but smooth work for me to write all the thousands of lines of highly error-prone code with basically zero chance to test it efficiently (this is the main pain point except for the enormous time sunk in the development itself). With audio it's very common to find mistakes first after many hours of error-less operation unlike with most other peripherals which either work first time and then forever (with minor exceptions due to different conditions of someone elses setup). And there are usually tens of such mistakes. It's probably the most tedious and dissatisfying work I've ever done (and I've done even crazy stuff like e.g. *marcan* does with the new Apples though in my case in much smaller scale). Which might explain why audio is either not being supported on SBCs/SoCs only partially or often not at all (btw. Linux internal audio interfaces changed quite significantly during the last 5 years - so even plain maintenance of a driver is PITA).

And that's why I rather devote the time to browsing and looking for an already working solution. I was even looking up codec chip which could be connected through **eUSB** and had 2 mics (not dmics) because that'd solve the issue for me - it's almost as low power as I2S+I2C connected codecs but with 0 development time because it's standard USB audio. Unfortunately I couldn't find any.

All in all thank you for asking me to help out, I feel honoured. I would very much like to say *yes* though I'm not yet in the position to devote my time to such a rabbit hole.

-------
Maybe it's time to create & sell a miniature "bridge" (ideally an ASIC or some DSP/uC but maybe even FPGA...) converting some ultra low power I2S+I2C codec (featuring at least 2 mics, several dmics etc.) to standard USB audio and offering eUSB instead of standard USB, so that integrators can just place it on PCB to have **0** effort full-featured audio with more or less the same low power consumption as a "native" codec (and those SoCs without eUSB would use a cheap miniature eUSB<->USB bridge which is generally well available).

Closed 2021-11-04.

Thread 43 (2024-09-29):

Freshly built doesn't boot

stonehencs, 2024-09-29:
Hello,

I'm so desperate that I had no other idea where to ask for help, so I'll try here.

I built a breadbee by myself and everything is in place/all soldered perfectly and all volts are there. Even windows recognizes the CH340E but no data is coming in on UART. I tried with different SPI NOR chips finally I stayed with W25Q256FV because of the large memory capacity of the chip. I even managed to run buildroot for the 5th time to generate the image which I was able to write to the SPI chip.

But after that I don't have much idea what could be wrong.
Anyone have any ideas?

Thanks in advance!

fifteenhex, 2024-09-29:
Congrats on building one! If you set the baud rate for your serial to 38400 (I think) do you see anything? The boot rom in the chip if it is working will print out some debug stuff.

I haven't touched this stuff in ages but I'll help you to get it going.

stonehencs, 2024-09-29:
First of all, thank you very much!
I tried but got nothing. At the moment I suspect that the crystal is not working because I tried 2 MSC313Es but they all had this problem.
I'll attach two pictures of how I did it, but first I had no way to write the SPi chip itself on the crib board so I improvised with a gold connector and some cable.

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

fifteenhex, 2024-09-30:
If you stick a multimeter in voltage mode on the crystal do you see anything?

stonehencs, 2024-09-30:
I can't see anything, so I suspect that's where the problem might be. But this is my last guess.

fifteenhex, 2024-09-30:
> I can't see anything, so I suspect that's where the problem might be. But this is my last guess.

Ok, you should check you are getting the correct voltages on the different rails.

stonehencs, 2024-09-30:
I have checked and there is the right voltage everywhere.

I ordered a new crystal, as soon as it arrives I will replace it and report back. Should be here in 2-3 working days.

stonehencs, 2024-10-07:
Sorry for the delay, I got the crystal, I managed to put it on and now I have about 1.5V there but it still won't start and I get nothing on UART. I checked all the voltages again and everything is there, the machine recognises the CH340 as before but spits out nothing.

stonehencs, 2024-10-09:
@fifteenhex I was wondering if there's any way I could measure if the chip is working?

fifteenhex, 2024-10-10:
> @fifteenhex I was wondering if there's any way I could measure if the chip is working?

Give me a day or so to get back to you. Work is crazy at the moment.

stonehencs, 2024-10-10:
Feel free and thank you for spending your free time on my problem.

fifteenhex, 2024-10-19:
@stonehencs

I think if you are seeing ~1.5v the oscillator is running. Try connecting minicom at 38400 baud and while it is connected to usb manually reset the chip by connecting a wire to the point between c37 and r23 (the reset circuit) and poking it on a 3.3v connection. You should see characters come out and that'll tell you what is wrong.

Also if you want to drop me a private email I can probably send you a working board so you can compare against yours.

stonehencs, 2024-10-20:
Unfortunately I have a windows computer so I tried what you described with a program called realterm. But it did not detect anything even though I tried many times.
I was thinking that the chip itself might be bad and then I made a breakout board (which hasn't arrived yet) and put together the basics based on your schematic, i.e. the SPI chip, the power sources and the decoupling capacitors. Maybe it will produce something.

I will gladly accept your offer if you really have a working piece. I've even thought that if you have the time and the capacity, I'll send you my board and see if you have more advanced tools to debug it.

My private email address is |hencs.bence@gmail.com| so if you saw the post I'll delete it from here.

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

pak-man, 2024-10-20:
Nowadays doing with electronics is paradise: basic tools are dirt cheap,
boards also, it´s easy to program, there are zillions of resources online.

I can only recommend buying few basic tools when working with digital
electronics: a dirt cheap logic analyzer can be had for less than 10$, even
as cheap a FIVE bucks. Ebay or aliexpress with "logic analyzer 24MHz 8
channels" and you´ll find a little jewel that does not break the bank. Use
some opensource software with it like pusleview (win/mac/linux) and go on
youtube for some hands-on learning.

You´ll learn a lot, you´ll spot problems, it´s worth every cent and minute
of your time. Sure it´s limited to 24MHz, but just define a slower clock
when you initialize your SPI bus, and it´s ok!

(My first logic analyzer weighted easily 30kg, took half of my desk, and
costed me a whole two months of summer job money - second hand)

Am So., 20. Okt. 2024 um 19:20 Uhr schrieb stonehencs <
***@***.***>:

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

stonehencs, 2024-10-22:
@pak-man
You're absolutely right, I was thinking mainly of an oscilloscope, but you're right that I can use a cheap logic analyzer to see if there's any movement on the SPI channel and UART.
Thanks for the idea!

fifteenhex, 2024-10-22:
@stonehencs one of the cheap analyzers that work with sigrok would be enough to check if its doing anything. But the oscillator running is a sign that the chip is doing something.
I send you a mail in a few days about sending a finished. On a trip at the moment.

stonehencs, 2024-10-30:
Does it have to be sigrok? Because the shop where I shop has one that is Saleae compatible.
link: https://www.hestore.hu/prod_10035503.html

pak-man, 2024-11-01:
It´s the same hardware, and feel free to use it with whatever software
works for your OS

Am Mi., 30. Okt. 2024 um 11:44 Uhr schrieb stonehencs <
***@***.***>:

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

stonehencs, 2024-11-03:
Okay, thank you. I've ordered it, and I'll let you know when it arrives and I've managed to make something with it.

stonehencs, 2024-11-09:
The loogic analyzer arrived and I used it right away after a few test runs on the arduino. I got quite interesting stuff I think although not so much unfortunately I don't understand it. I will upload the pictures here and leave a link where you can download the data as csv or open the session file with Saleae Logic.

I connected a channel to each data leg of the Spi chip, the crystal and the uart tx/rx output leg. I noticed that the crystal gives an output that is when it is 24mhz and when it is 12 mhz( you will see it better in the picture). On the uart concretely there is a tiny movement. This is what I was able to get some ASCII out of it into Realterm: CE0EFE3E0EC0CE003000 and it repeats this after every reset.
Link: https://drive.google.com/drive/folders/1Rbi9VHoY2qpa1jU66Z_scIadBhbOR_HJ?usp=drive_link

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

stonehencs, 2024-11-11:
I managed to do the break board version with the basics (i.e. the crystal, reset, and basic current rails) but I get the same ones as I posted in the previous post.

fifteenhex, 2024-11-14:
I'll try to send a dump of a working board you can write to your flash this weekend.
It does look like it's accessing the SPI flash though and that sort of shows it's working.

stonehencs, 2024-11-16:
I managed to get it to boot!!!! I regenerated the whole thing from scratch on a separate virtual machine and one of the LEDs lit up. However, my uart access was not easy because I had no normal baudrate so I had to measure it and ended up with 50253 baudrate. Finally I got this:
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
stonehencs, 2024-12-02:
I tried, but it didn't boot either. But now it gives a new error, that it is unable to mount the root fs.

log:
[putty.log](https://github.com/user-attachments/files/17983088/putty.log)

stonehencs, 2024-12-07:
@fifteenhex I had an idea that maybe it was the SPI chip I was using that was defective so I ordered the same one as the one in the components layout and once I ordered it I ordered another kind of crystal.
I put it together last night and guess what with the .bin file you sent me: it booted up!!!!

I tried with the image I generated but got the same error: `kernel BUG at crypto/algapi.c:461!`.

Were you able to find out why it would throw this error?

stonehencs, 2024-12-17:
@fifteenhex I managed to generate a working firmware after about 3 different ubuntu versions. I tried to add an Apache in the config but got the error that it can't find GLIBC_2.33. I checked and it uses an older version in buildroot. I got the same when I tried to add a simple custom package that would just print "Hello World". And after I took them out to see if it would run without it then it got stuck with the GLIBC error.

How can I update or remove the error?
Boot log for the working version:
[putty (2).log](https://github.com/user-attachments/files/18168342/putty.2.log)

Would you mind checking that I have configured the package correctly?
Link to the repo: https://github.com/stonehencs/costum_package

fifteenhex, 2024-12-24:
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

The buildroot setup should give you a private key on your build machine and that setup on the board. I haven't built it in a while.
For gpio you should see another chip that is the main gpio controller too...
I'm going to build stuff again and try it out and see what state I let it in. I would have done it sooner but I've been busy and my PC has been dying.

stonehencs, 2024-12-24:
Sorry to hear what has happened to your computer?
I've noticed that every time I clone from github, make finds different commands when I tab, and even when I manage to build apach2, it doesn't install on the system because I can't find any files related to it.

stonehencs, 2025-01-07:
@fifteenhexI'm trying to write a C application where I control the gpio in the memory address but I can't find the right value anywhere. I tried to find out from here:

```
$ cat /proc/iomem | grep -i gpio
1f001e00-1f001fff : 1f001e00.gpio_pm
1f207800-1f2079ff : 1f207800.gpio
```
but it didn't work for my program.
My code: (sorry for the language)
(https://github.com/stonehencs/costum_package/blob/main/br2apps/package/bence/raw/gpio_teszt.c)

Can you help me what it is or where I can find it?

stonehencs, 2025-01-17:
Sorry to bother you, but did you manage to build the image file or rebuild the bug? Any idea how to find the memory address?

Thank you in advance

stonehencs, 2025-01-23:
@fifteenhex I tried, especially now that I know that's the official gpio address. But I can't get it to work, it always throws an error on nmap call or memory errors. Maybe you could send me some example code or a web page with this documented?
Link my code: https://github.com/stonehencs/costum_package/blob/main/br2apps/package/bence/raw/gpio_teszt.c

 My other question is that I tried to add a read/write partition and found that it already automatically creates one and mounts it in rw directory. However, if I create one and then try to copy it to the rw partition in genimage.cfg, it will find the files I put in it, but it throws this error:

```
jffs2: error: (72) jffs2_build_inode_fragtree: Add node to tree failed -22
jffs2: error: (72) jffs2_do_read_inode_internal: Failed to build final fragtree for inode #2: error -22
```

fifteenhex, 2025-01-24:
I'm not sure about the rw partition issue but I think the GPIO one is one of the options in the kernel config like `CONFIG_STRICT_DEVMEM`.

stonehencs, 2025-01-27:
So I just enable it and I should have proper access to the memory?

However, do you remember where you created the rw partition? Or just by fstab and from the dts partition? I mean, is it created by the system at boot time and not during a build?

fifteenhex, 2025-02-01:
The r/w partition should be in the dts under the nor flash node and I think there is a script that is run on boot in /etc/init.d/ that tries to mount it (and maybe run the jffs2 format thing if needed?).

stonehencs, 2025-02-06:
I couldn't find anything there except a script to create the /rw/dropbear directory. I found that it is also set to automount in fstab.

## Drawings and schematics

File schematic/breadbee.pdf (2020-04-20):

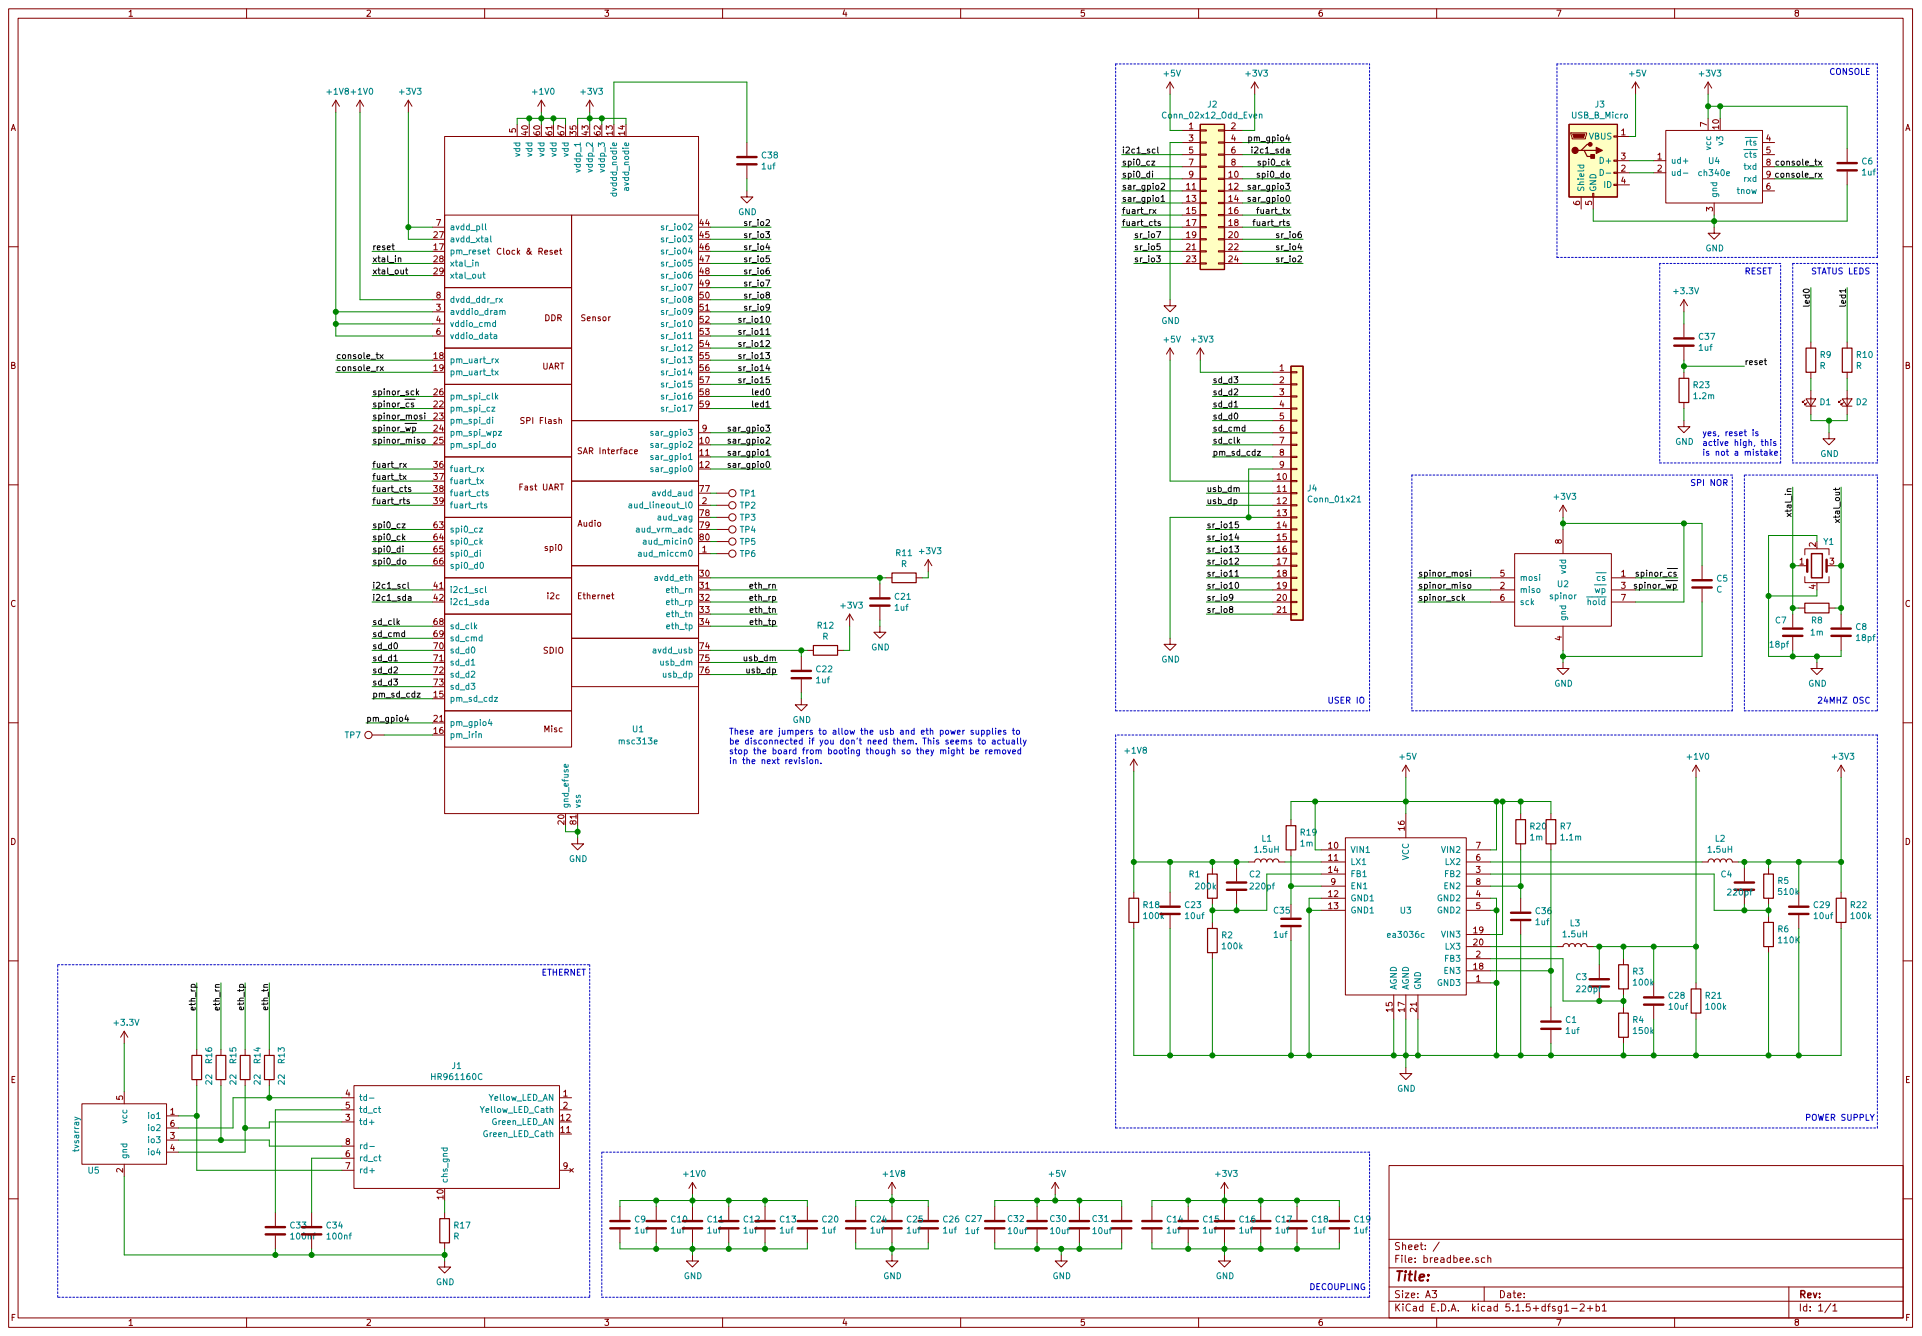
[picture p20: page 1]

spinor Audio Clock & Reset DDR

These are jumpers to allow the usb and eth power supplies to
be disconnected if you don't need them. This seems to actually
stop the board from booting though so they might be removed

ETHERNET

Id: 1/1 Title: File: breadbee.sch Sheet: / R15 22

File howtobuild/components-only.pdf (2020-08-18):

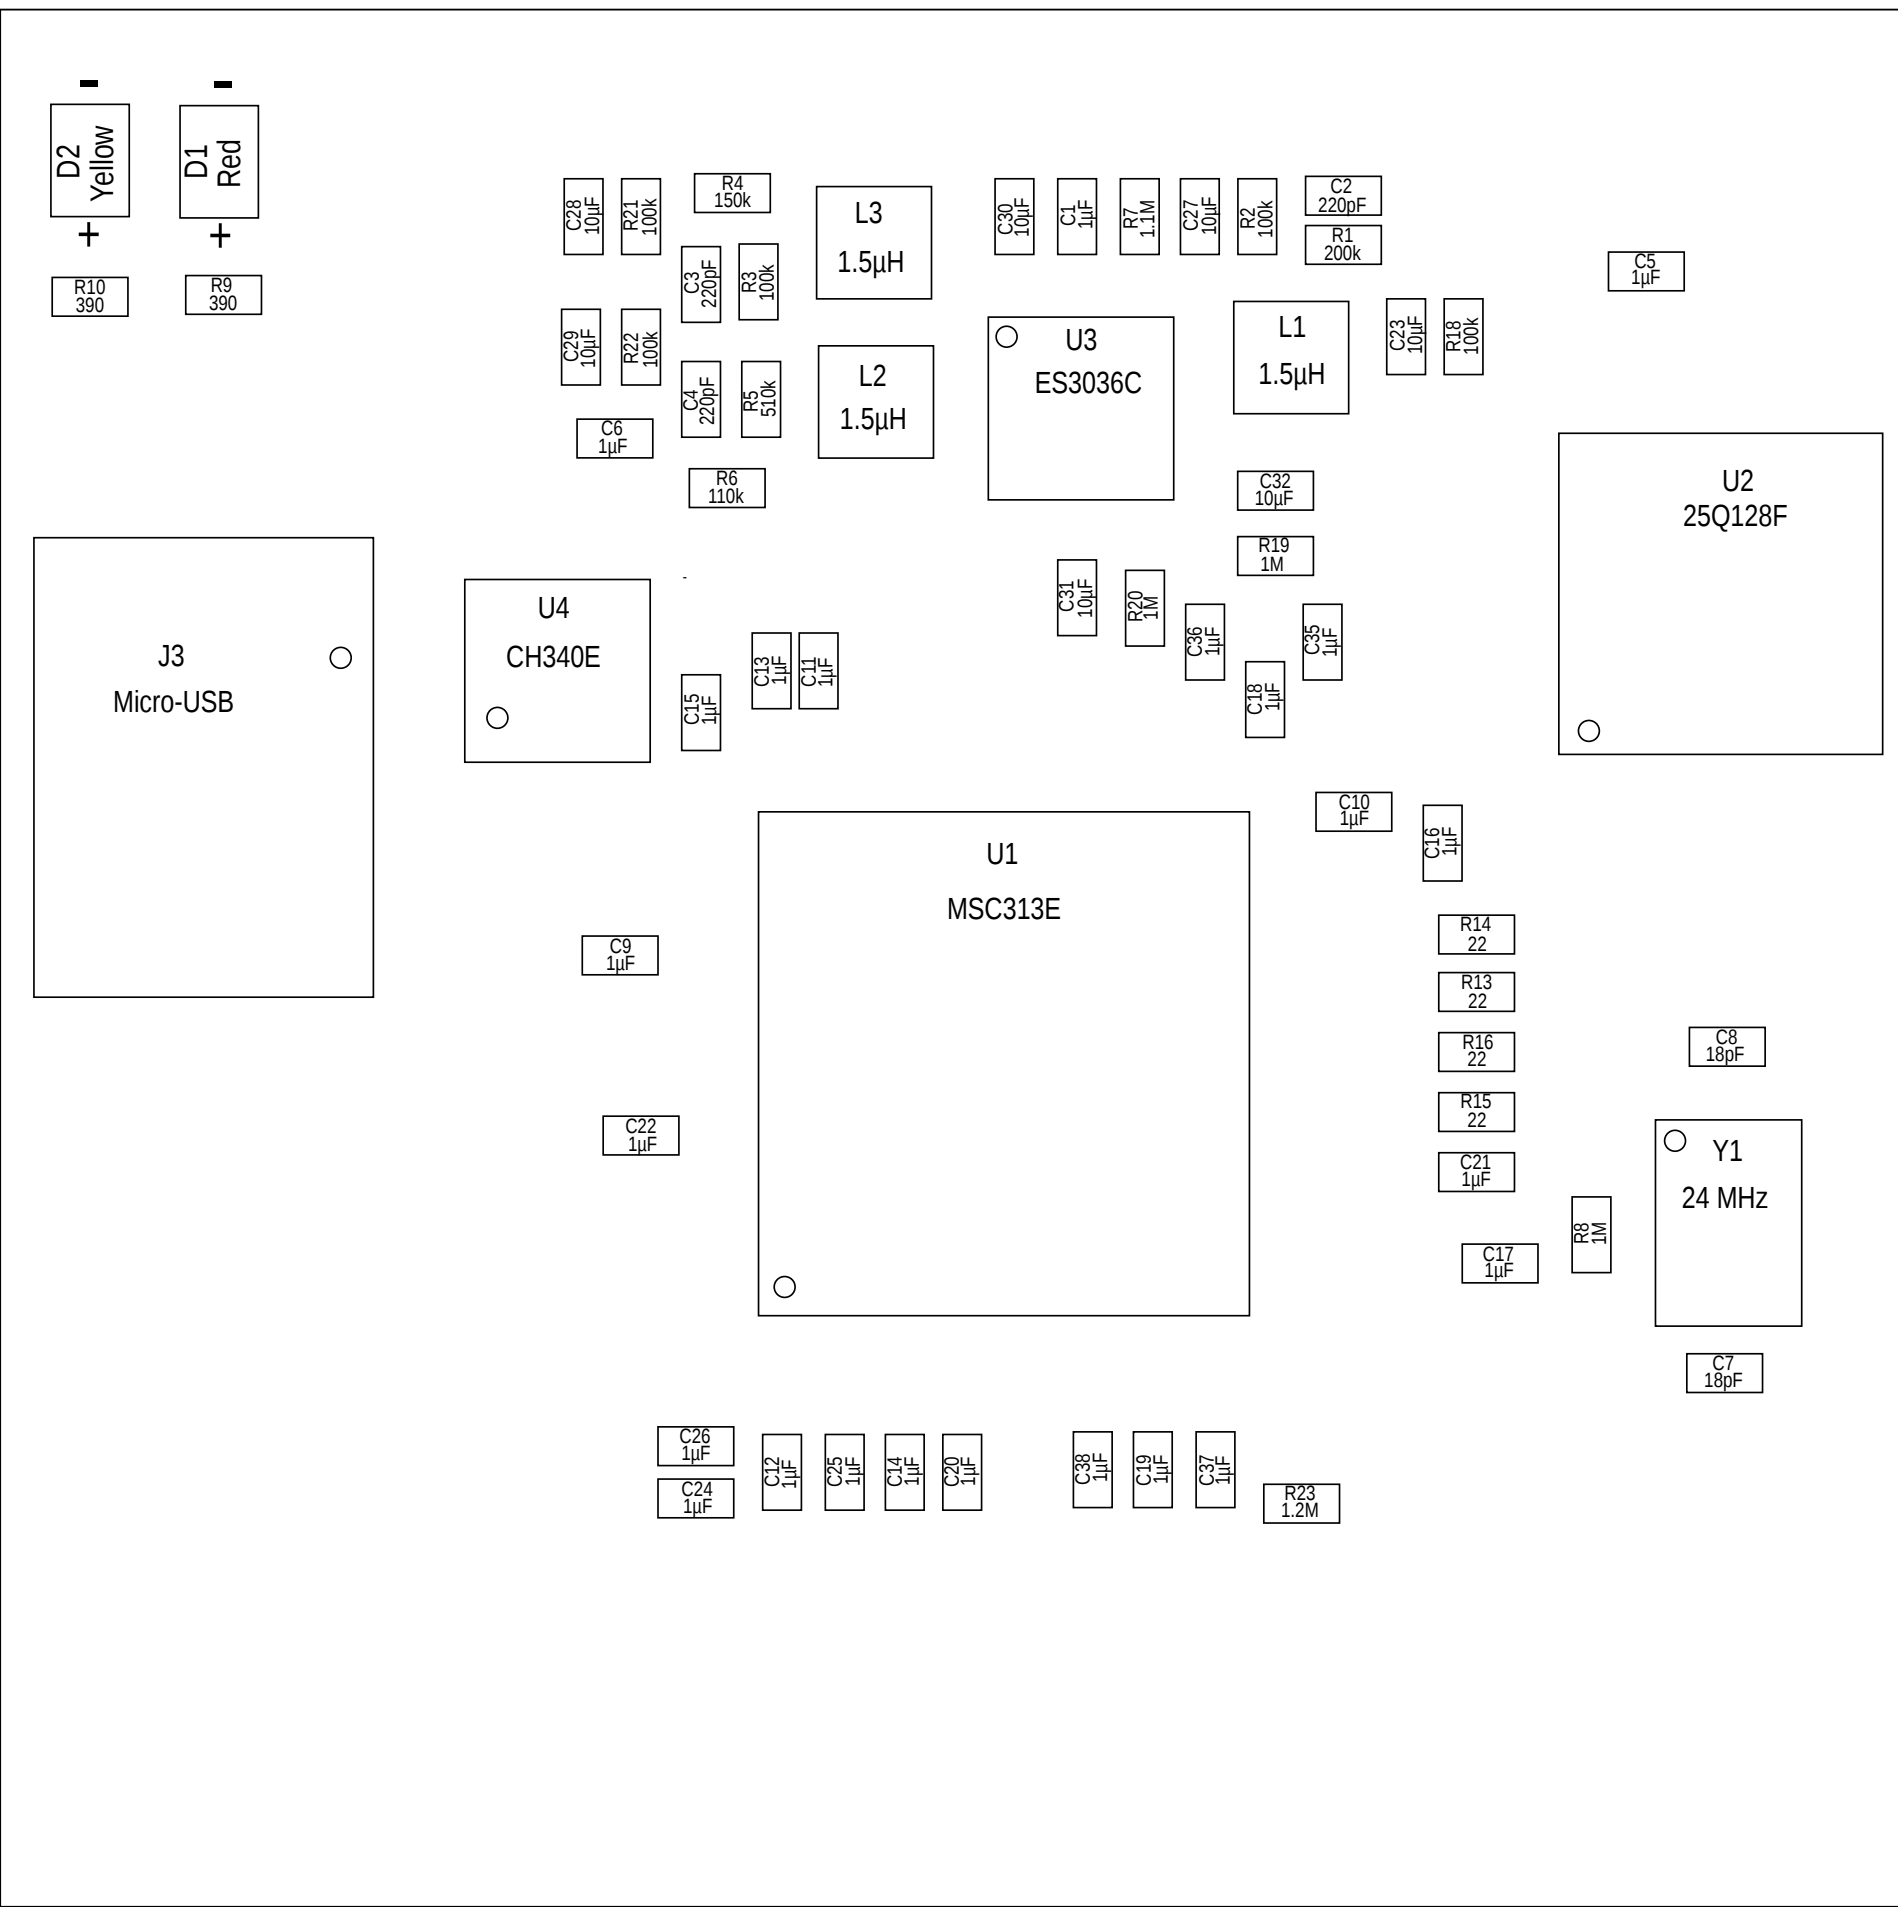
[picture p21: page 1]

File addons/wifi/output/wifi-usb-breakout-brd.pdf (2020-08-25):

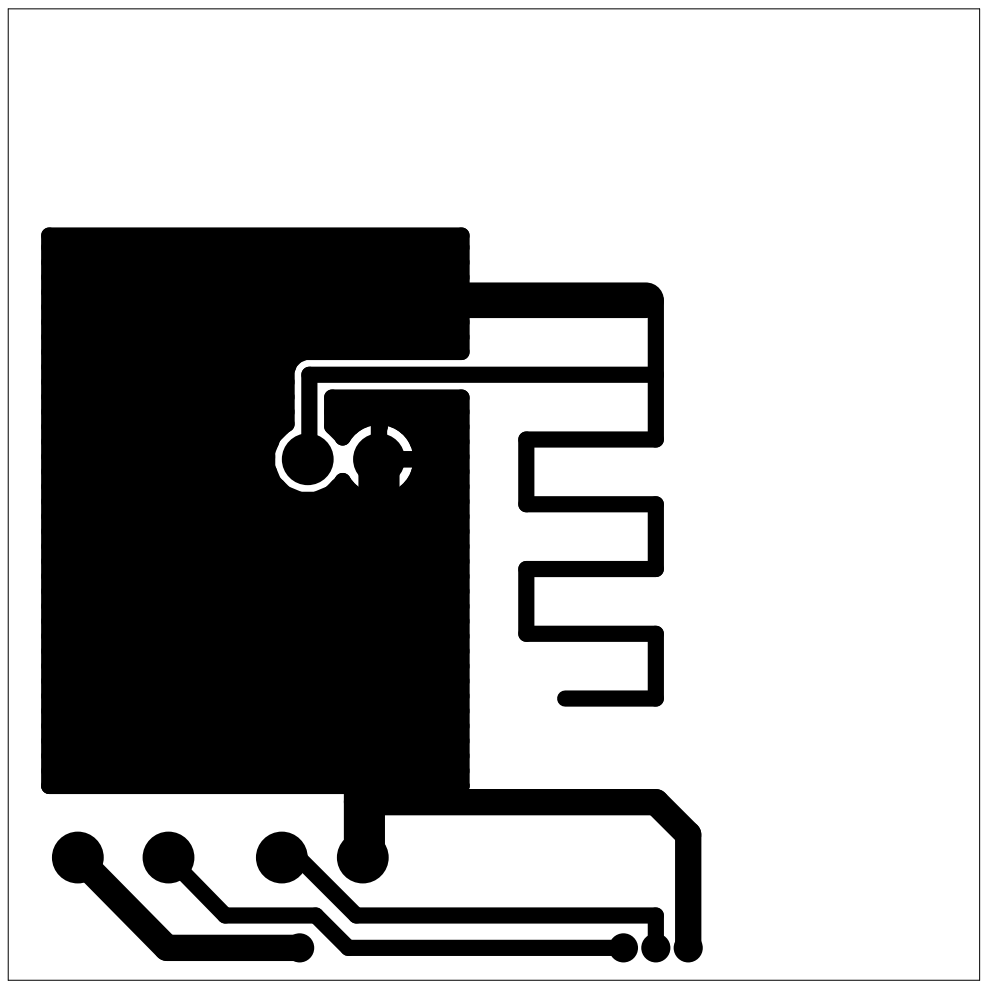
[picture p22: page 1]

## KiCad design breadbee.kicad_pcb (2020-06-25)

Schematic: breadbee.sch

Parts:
C1, C6, C9, C10, C11, C12, C13, C14, C15, C16, C17, C18, C19, C20, C21, C22, C24, C25, C26, C27, C35, C36, C37, C38: 1uf; C_0402_1005Metric
C2, C3, C4: 220pf; C_0402_1005Metric
C5: 1uF; C_0402_1005Metric
C7, C8: 18pf; C_0402_1005Metric
C23, C28, C29, C30, C31, C32: 10uf; C_0402_1005Metric
C33, C34: 100nf; C_0402_1005Metric
D1, D2: LED_Small; LED_0805_2012Metric
J1: HR961160C
J2: Conn_02x12_Odd_Even; PinHeader_2x12_P2.54mm_Vertical
J3: USB_B_Micro; USB-MICRO-B
J4: Conn_01x21; PinHeader_1x21_P1.00mm_Vertical
L1, L2, L3: 1.5uH; L_Taiyo-Yuden_MD-2020
R1: 200k; R_0402_1005Metric
R2, R3, R18, R21, R22: 100k; R_0402_1005Metric
R4: 150k; R_0402_1005Metric
R5: 510k; R_0402_1005Metric
R6: 110K; R_0402_1005Metric
R7: 1.1m; R_0402_1005Metric
R8, R19, R20: 1m; R_0402_1005Metric
R9, R10: 390; R_0402_1005Metric
R11, R12, R17: 0; R_0402_1005Metric
R13, R14, R15, R16: 22; R_0402_1005Metric
R23: 1.2m; R_0402_1005Metric
TP1, TP2, TP3, TP4, TP5, TP6, TP7: TestPoint; TestPoint_Pad_D1.0mm
U1: msc313e; QFN-80_EP_8x8_Pitch0.35mm
U2: spinor; wson8-8x6mm
U3: ea3036c; UQFN-20-1EP_3x3mm_P0.4mm_EP1.85x1.85mm_ThermalVias
U4: ch340e; MSOP-10_3x3mm_P0.5mm
U5: tvsarray; SOT-23-6
Y1: Crystal_GND24; Crystal_SMD_Abracon_ABM8G-4Pin_3.2x2.5mm

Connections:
+1V0: C3.1, C9.1, C10.1, C11.1, C12.1, C13.1, C20.1, C28.1, L3.2, R3.1, R21.1, U1.5, U1.8, U1.40, U1.60, U1.61, U1.67
+1V8: C2.1, C23.1, C24.1, C25.1, C26.1, L1.1, R1.1, R18.1, U1.3, U1.4, U1.6
+3V3: C4.1, C5.1, C6.1, C14.1, C15.1, C16.1, C17.1, C18.1, C19.1, C29.1, C37.1, J2.2, J4.1, L2.2, R5.1, R11.1, R12.1, R22.1, U1.7, U1.14, U1.27, U1.35, U1.43, U1.62, U2.7, U2.8, U4.7, U4.10, U5.5
+5V: C27.1, C30.1, C31.1, C32.1, J2.1, J3.1, J4.10, R7.1, R19.1, R20.1, U3.7, U3.10, U3.16, U3.19
/console_rx: U1.19, U4.9
/console_tx: U1.18, U4.8
/eth_rn: R15.2, U1.31
/eth_rp: R16.2, U1.32
/eth_tn: R13.2, U1.33
/eth_tp: R14.2, U1.34
/fuart_cts: J2.17, U1.38
/fuart_rts: J2.18, U1.39
/fuart_rx: J2.15, U1.36
/fuart_tx: J2.16, U1.37
/i2c1_scl: J2.5, U1.41
/i2c1_sda: J2.6, U1.42
/led0: R9.1, U1.58
/led1: R10.1, U1.59
/pm_gpio4: J2.4, U1.21
/pm_sd_cdz: J4.8, U1.15
/reset: C37.2, R23.1, U1.17
/sar_gpio0: J2.14, U1.12
/sar_gpio1: J2.13, U1.11
/sar_gpio2: J2.11, U1.10
/sar_gpio3: J2.12, U1.9
/sd_clk: J4.7, U1.68
/sd_cmd: J4.6, U1.69
/sd_d0: J4.5, U1.70
/sd_d1: J4.4, U1.71
/sd_d2: J4.3, U1.72
/sd_d3: J4.2, U1.73
/spi0_ck: J2.8, U1.64
/spi0_cz: J2.7, U1.63
/spi0_di: J2.9, U1.65
/spi0_do: J2.10, U1.66
/spinor_miso: U1.25, U2.2
/spinor_mosi: U1.23, U2.5
/spinor_sck: U1.26, U2.6
/spinor_~cs: U1.22, U2.1
/spinor_~wp: U1.24, U2.3
/sr_io2: J2.24, U1.44
/sr_io3: J2.23, U1.45
/sr_io4: J2.22, U1.46
/sr_io5: J2.21, U1.47
/sr_io6: J2.20, U1.48
/sr_io7: J2.19, U1.49
/sr_io8: J4.21, U1.50
/sr_io9: J4.20, U1.51
/sr_io10: J4.19, U1.52
/sr_io11: J4.18, U1.53
/sr_io12: J4.17, U1.54
/sr_io13: J4.16, U1.55
/sr_io14: J4.15, U1.56
/sr_io15: J4.14, U1.57
/usb_dm: J4.11, U1.75
/usb_dp: J4.12, U1.76
/xtal_in: C7.1, R8.2, U1.28, Y1.1
/xtal_out: C8.1, R8.1, U1.29, Y1.3
GND: C1.2, C5.2, C6.2, C7.2, C8.2, C9.2, C10.2, C11.2, C12.2, C13.2, C14.2, C15.2, C16.2, C17.2, C18.2, C19.2, C20.2, C21.2, C22.2, C23.2, C24.2, C25.2, C26.2, C27.2, C28.2, C29.2, C30.2, C31.2, C32.2, C33.2, C34.2, C35.2, C36.2, C38.2, D1.1, D2.1, J2.3, J3.5, J4.9, J4.13, R2.2, R4.2, R6.2, R17.2, R18.2, R21.2, R22.2, R23.2, U1.20, U1.81, U2.4, U3.1, U3.4, U3.5, U3.12, U3.13, U3.15, U3.17, U3.21, U4.3, U5.2, Y1.2, Y1.4
unnamed: C1.1, R7.2, U3.18
unnamed: C2.2, R1.2, R2.1, U3.14
unnamed: C3.2, R3.2, R4.1, U3.2
unnamed: C4.2, R5.2, R6.1, U3.3
unnamed: C21.1, R11.2, U1.30
unnamed: C22.1, R12.2, U1.74
unnamed: C33.1, J1.5
unnamed: C34.1, J1.6
unnamed: C35.1, R19.2, U3.9
unnamed: C36.1, R20.2, U3.8
unnamed: C38.1, U1.13
unnamed: D1.2, R9.2
unnamed: D2.2, R10.2
unnamed: J1.3, R14.1, U5.4
unnamed: J1.4, R13.1, U5.6
unnamed: J1.7, R16.1, U5.1
unnamed: J1.8, R15.1, U5.3
unnamed: J1.10, R17.1
unnamed: J3.2, U4.2
unnamed: J3.3, U4.1
unnamed: L1.2, U3.11
unnamed: L2.1, U3.6
unnamed: L3.1, U3.20
unnamed: TP1.1, U1.77
unnamed: TP2.1, U1.2
unnamed: TP3.1, U1.78
unnamed: TP4.1, U1.79
unnamed: TP5.1, U1.80
unnamed: TP6.1, U1.1
unnamed: TP7.1, U1.16

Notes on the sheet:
CONSOLE
STATUS LEDS
RESET
yes, reset is active high, this is not a mistake
24MHZ OSC
SPI NOR
USER IO
POWER SUPPLY
ETHERNET
DECOUPLING
These are jumpers to allow the usb and eth power supplies to be disconnected if you don't need them. This seems to actually stop the board from booting though so they might be removed in the next revision.
The enables are configured to sequence the power rails in accordance with the datasheet.

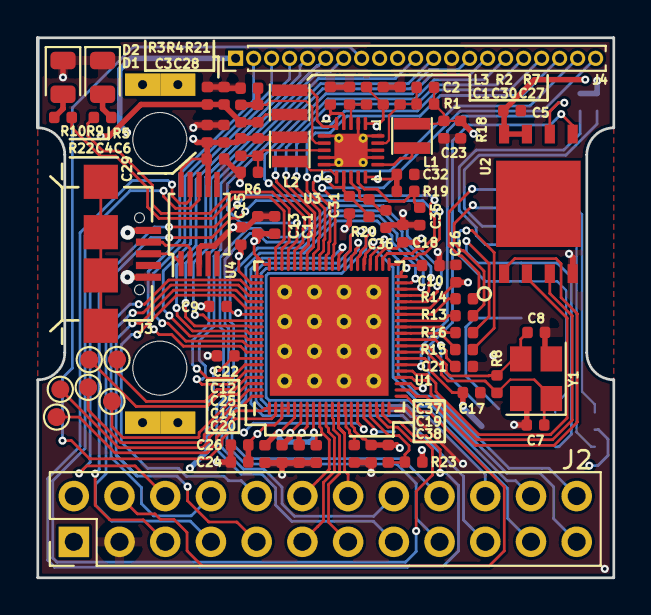
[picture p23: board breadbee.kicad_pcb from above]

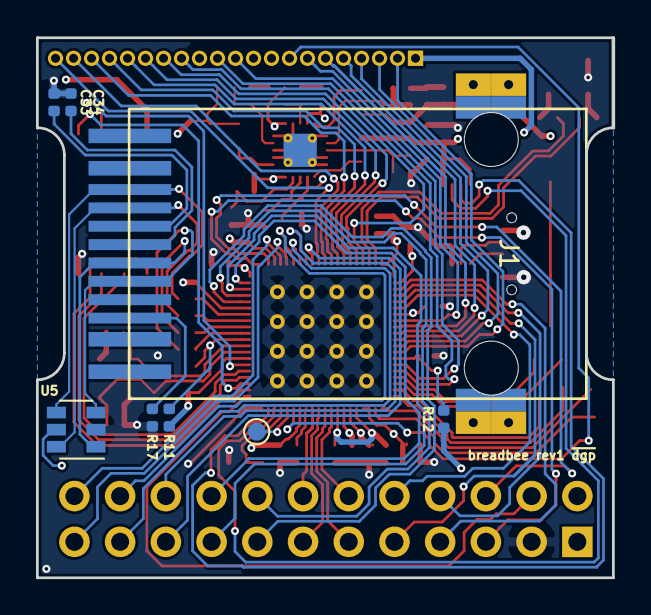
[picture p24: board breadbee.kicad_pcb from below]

Board: 4 copper layers, 32.0 x 30.0 mm, 83 parts (8 on the bottom side), 89 nets.

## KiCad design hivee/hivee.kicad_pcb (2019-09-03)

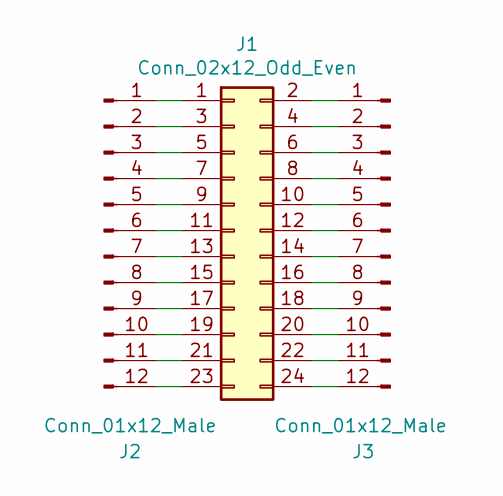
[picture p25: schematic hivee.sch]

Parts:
J1: Conn_02x12_Odd_Even; PinSocket_2x12_P2.54mm_Vertical
J2, J3: Conn_01x12_Male; PinHeader_1x12_P2.54mm_Vertical

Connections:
unnamed: J1.1, J2.1
unnamed: J1.2, J3.1
unnamed: J1.3, J2.2
unnamed: J1.4, J3.2
unnamed: J1.5, J2.3
unnamed: J1.6, J3.3
unnamed: J1.7, J2.4
unnamed: J1.8, J3.4
unnamed: J1.9, J2.5
unnamed: J1.10, J3.5
unnamed: J1.11, J2.6
unnamed: J1.12, J3.6
unnamed: J1.13, J2.7
unnamed: J1.14, J3.7
unnamed: J1.15, J2.8
unnamed: J1.16, J3.8
unnamed: J1.17, J2.9
unnamed: J1.18, J3.9
unnamed: J1.19, J2.10
unnamed: J1.20, J3.10
unnamed: J1.21, J2.11
unnamed: J1.22, J3.11
unnamed: J1.23, J2.12
unnamed: J1.24, J3.12

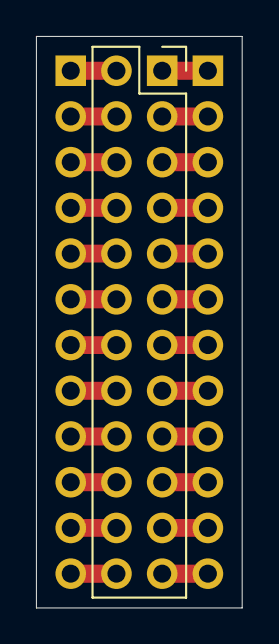
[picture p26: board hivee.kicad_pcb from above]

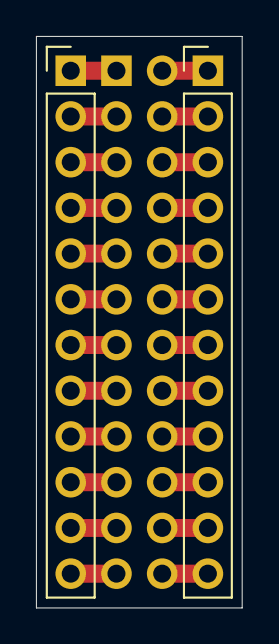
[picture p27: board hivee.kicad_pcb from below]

Board: 2 copper layers, 11.4 x 31.8 mm, 3 parts (2 on the bottom side), 24 nets.

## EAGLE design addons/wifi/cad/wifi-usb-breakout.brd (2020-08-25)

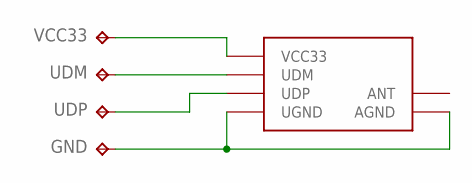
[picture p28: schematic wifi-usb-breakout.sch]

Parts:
GND: TPTP09R; TP09R
U$1: USB-WIFI-MODULE
UDM: TPTP09R; TP09R
UDP: TPTP09R; TP09R
VCC33: TPTP09R; TP09R

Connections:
unnamed: U$1.P$1 (VCC33), VCC33.TP
unnamed: U$1.P$2 (UDM), UDM.TP
unnamed: U$1.P$3 (UDP), UDP.TP
unnamed: GND.TP, U$1.P$4 (UGND), U$1.P$5 (AGND)

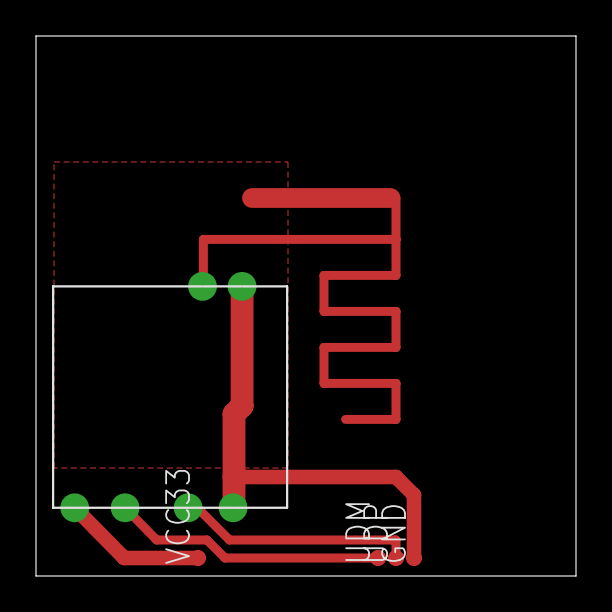
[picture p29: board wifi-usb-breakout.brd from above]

Board: 2 copper layers, 30.0 x 30.0 mm, 5 parts (0 on the bottom side), 4 nets.

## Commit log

2019-05-24 Add pin table for j2
2019-05-30 Fix some component values
    [breadbee.sch]
2019-06-14 Fix screw up with the sar pins
    [breadbee.kicad_pcb, breadbee.sch]
2019-06-15 Clean up schematic. Add PDF plot of schematic.
    [breadbee.sch]
2019-06-19 Add hivee breadboard adapter
    [hivee.kicad_pcb, hivee.sch]
2019-07-09 Add scan of board
2019-07-09 Move component side board scan into sub directory
2019-07-10 Add links to relevant drivers
2019-07-10 Add small 1mm -> 2.54mm break out.
    [slice_alltheios.kicad_pcb, slice_alltheios.sch]
2019-09-03 USB SDIO io breakout
    [slice_sdusbios-B_Cu.gbr, slice_sdusbios-B_Mask.gbr, slice_sdusbios-B_Paste.gbr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]
2019-09-03 Fix solder mask.
    [breadbee-B_Cu.gbr, breadbee-B_Mask.gbr, breadbee-B_Paste.gbr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]
2020-04-20 Add missing symbol/footprint tables
    The repository is missing the fp-lib-table and sym-lib-table files which
    makes problems when editing/viewing schematics on freshly cloned repo.
    The provided tables uses ${KIPRJMOD} to be independent from the path in
    the file system.
2020-04-20 pcb: fix the sloppy solder mask
    [breadbee.kicad_pcb]
2020-04-20 pcb/footprint: fix up the thin pins on the soc
    [breadbee.kicad_pcb]
2020-04-20 sch: add missing values
    [breadbee.sch]
2020-04-20 Add the usb/sd card breakout
    [slice_sdusbios.kicad_pcb]
2020-04-23 Missing values, public bom link
    [breadbee.kicad_pcb, breadbee.sch]
2020-06-07 rev 1+ - fix another weird pad
    [breadbee-B_Cu.gbr, breadbee-B_Mask.gbr, breadbee-B_Paste.gbr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]
2020-06-25 pcb: remove redundant fragment of usb_dp
    On a wire connecting the usb_dp to the header pin there was a redundant
    fragment that was going on top of the actual wire connecting the whole
    net. A small part of this wire had an offset making the wire ticker in
    one place as well.
    I noticed that by pure luck by manually going over the wire (after
    pressing I). Unfortunately I don't know any method of automatically
    finding such problems.
    Note that in order to keep this change as small as possible I did not
    run the refill of the bottom layer even though it could flow a little
    more now that the thicker part of a wire is gone.
    [breadbee.kicad_pcb]
2020-06-25 footprints: fix courtyard of wson8-8x6mm
    One edge (left one) of the courtyard box in this package was drawn on
    the wrong layer (Dwgs.User instead of F.CrtYd) like others. While
    hard/impossible to see by an eye, for the Kicad this was unclosed shape
    making it complain in DRC if courtyard checks are enabled.
    Note that in order to make this change small and easy to merge in case
    of conflicts, I did not include the change on the kicad_pcb file after
    updating the footprint. You have to click on the "Update footprint from
    library" in the properties window of U2 yourself.
2020-06-25 footprints: fix courtyard width on wson8-8x6mm
    While I was editing the courtyard of this footprint I noticed that it
    has a default width of 0.15mm. The Kicad Library Conventions point 5.3
    (https://kicad-pcb.org/libraries/klc/F5.3/) specifies, however, that
    courtyard with should be 0.05mm
2020-07-04 howtobuild: provide a printable reference for components
    This adds:
    - components-layout.svg : source file (inkscape)
    - components-only.pdf : components only, printable format
    - components-copper.jpg : components on top of copper tracks
    - components-photo.jpg : components on top of finished board photo
    howtobuild was updated to mention it.
2020-07-11 howtobuild: update the components layout
    - D2 (top left) is the yellow LED
    - D1 (right) is the red LED
    Also added locations of a few reference voltages to ease debugging.
2020-08-22 Move the addons out into their own repo: https://github.com/breadbee/breadbee_addons
    [slice_alltheios.kicad_pcb, slice_alltheios.sch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]
2020-08-24 addons: add info about how to easily add a cheap WiFi module
    It's particularly easy to add WiFi support to the breadbee, so let's
    document how this can be done, providing configs, patches, schematics,
    boards and photos.
    [wifi-usb-breakout.brd, wifi-usb-breakout.sch]
